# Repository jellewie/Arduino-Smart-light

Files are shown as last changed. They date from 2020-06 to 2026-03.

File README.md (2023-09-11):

# Smart clock
A smart 3D printed light clock/lamp, that includes, but is not limited to; WIFI and manual control, Clock mode, multiple animations, and transitions.

If you have interest in buying one and live in The Netherlands, feel free to contact me.

You can skip to [Quick start guide](#quick-start-guide) if you already own a smart-clock, and just want to run the set-up.

You can skip to [OTA updater](#ota-over-the-air-update) if you just want to update it.

# Index
<details><summary>Show/hide</summary><p>

 - [Quick start guide](#quick-start-guide)
 - [Creating a unit](#creating-a-unit)
    - [Hardware](#hardware)
    - [Creating the model](#creating-the-model)
       - [Desk model](#desk-model)
       - [Wall model](#wall-model)
          - [3D printed only](#3d-printed-only)
          - [CNC](#cnc)
    - [PCB & wires](#pcb--wires)
    - [Firmware ](#firmware)
       - [Compile](#compile)
       - [BIN](#bin)
 - [Features](#features)
    - [Button](#button)
    - [LED status](#led-status)
    - [Potentiometer](#potentiometer)
    - [WIFI page](#wifi-page)
       - [Setup](#setup)
       - [Getting it’s IP](#getting-its-ip)
       - [Control](#control)
       - [Soft settings](#soft-settings)
       - [Clock mode](#clock-mode)
       - [Task List](#task-list)
       - [OTA (Over The Air update)](#ota-over-the-air-update)
       - [Full reset](#full-reset)
 - [Specifications ](#specifications)
    - [Input voltage](#input-voltage)
    - [Power consumption](#power-consumption)
 - [Appendix](#appendix)
</p></details>

# Quick start guide
Follow the following steps to setup the lamp, stop after the first step if you do not want to set up Wi-Fi.
1.	Connect a proper power supply. The LEDs will blink shortly a soft white for a split second to show that bootup was successful.
2.	The [potmeters](#pot-meter) or [button](#button) will change the light.

**Optional for WIFI:**
1.	Long press the button, this will make the LEDs go PURPLE/RED/PURPLE/RED this means it is trying to connect to Wi-Fi, if this takes more than 10 seconds it will have created an Access Point. (Long press the button again to cancel this setup)
2.	Connect to this Access Point, by default it will be called “smart-clock”.
3.	When connected go to [192.168.4.1](http://192.168.4.1/) this will show a page where the WIFI name (SSID) and password (Password) can be set, do not forget to submit to apply. Other settings on this page are explained in [soft settings](#soft-settings), for example 'Clockoffset' is the rotation of the LEDs (there are 60 LEDs so filling in 30 will rotate the clock by 50%). 
~~The light will also try to make a captive portal to prompt you to login and setup these settings. Sadly, this only works with HTTP, use the mentioned IP if the device does not prompt the login page ([Not working as of now, Known issue](https://github.com/jellewie/Arduino-Smart-light/issues/28))~~ 
4.	When the device is connected to WIFI it can be accessed by its IP address, but on devices who support mDNS, like Windows and Apple, [smart-clock.local/](http://smart-clock.local/) can also be used.

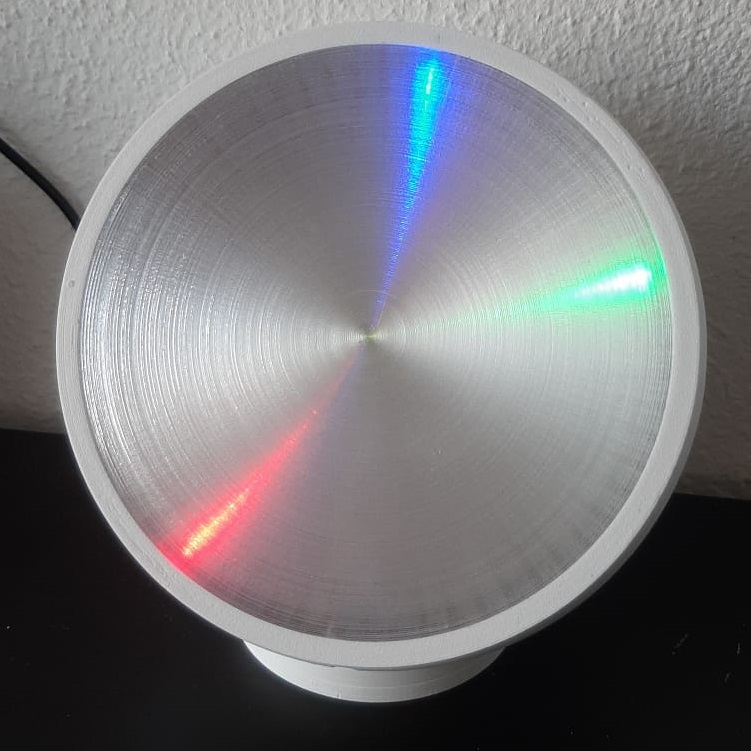
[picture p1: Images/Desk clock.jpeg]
Desk clock image

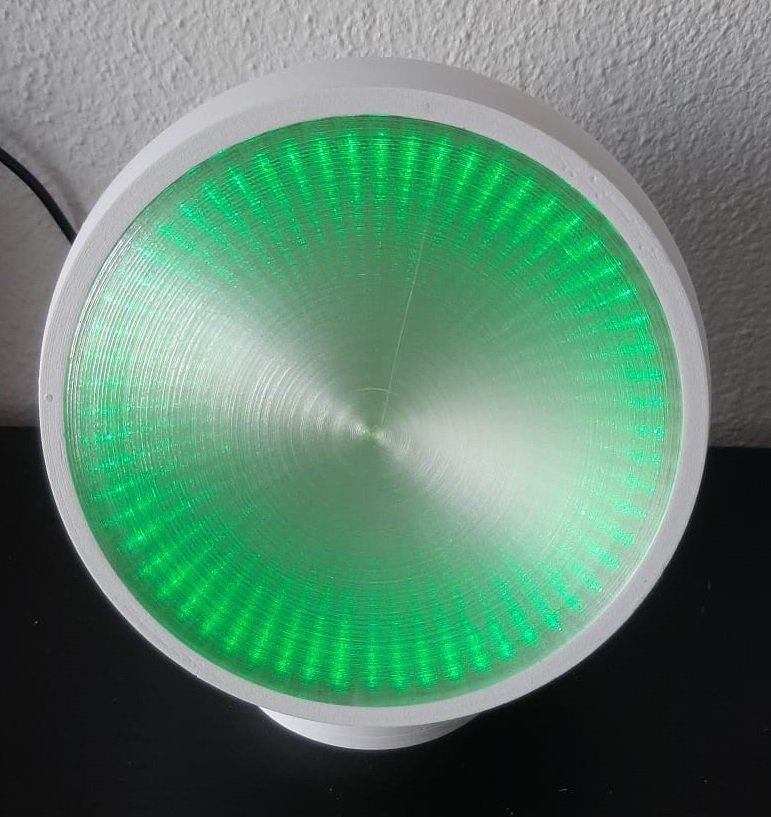
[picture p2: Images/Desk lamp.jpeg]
Desk lamp image


# Creating a unit
## Hardware
- A [PCB for the lamp/wall model](https://easyeda.com/jellewietsma/smart-light), or a lot of patient copying the schematic and doing it by hand.
- Parts listed in the [BOM](BOM.md) (or the BOM on EasyEDA), these include resistors, capacitors, buttons, potmeters, and an ESP32 as examples.
- An [model](#creating-the-model) to put everything in. This can either be completly 3D printed, or CNCed, and can also differ in model itzelf like the [DESK](#desk-model) or the [WALL](#wall-model) model.

## Creating the model
There multiple types of model, the '[DESK model](#desk-model)' is used in this readme as example project. But the other models have the same features, just a different shape. 

All STL files for 3D-printing have a predefined tolerance of 0.2mm build-in.
### Desk model
The model is [Desk.ipt](3DModel/Desk/Desk.ipt), for this model there are 4 files that need to be printed.
1.	[Lamp body.stl](3DModel/Desk/Body.stl) is the main body. It is suggested to do at least (0.4mm*3lines=1.2mm) walls so light will not shine though as much. It is printed on its face (like the STL orientation) and only the inner part needs a bit of support (overhang angle 90 degrees, density 2%).
2.	[Lamp shield.stl](3DModel/Desk/Shield.stl) is just a simple shield to add aluminium foil on, and will be intern so can be printed quick and dirty.
3.	[Lamp stand.stl](3DModel/Desk/Stand.stl) can have 3 times a pair embedded magnets in it, if the magnets are desired a layer pause need to be used. this model should be printed in the normal standing position on the round flat part.
4.	[Diffuser.gcode](3DModel/Desk/Diffuser.gcode) A perfect spiral Gcode, this can be created with [Jespers Perfect Spiral-Gcode](https://github.com/jespertheend/spiral-gcode). Altough a STL file is also included.

### Wall model
This model and PCB is 'Work In Progress'!

There are 2 variants, and fully 3d printed model, and a CNC model.

#### 3D printed only
The model is [Wall Clock.ipt](3DModel/Wall/Wall%20Clock.ipt), for this model there are 2 files that need to be printed.
1.	[Clock Top.stl](3DModel/Wall/Clock%20Top.stl) This is the top of the clock, which houses the PCB controls.
2.	[Clock x2.stl](3DModel/Wall/Clock%20x2.stl) This needs to be printed twice, and is the bottom left and right.

#### CNC
The model is [Wall Clock CNC.ipt](3DModel/Wall/Wall%20Clock&20CNC.ipt).
1.  [Wall Clock CNC.ipt](3DModel/Wall/Wall%20Clock&20CNC.ipt) This is the part that needs to be cut, it has thicker walls and no LED seperates
2.	The CNC .ipt mentioned above does have hidden LED seperates in the file, the idea was to 3d print them but this is still a WIP idea thing.

## PCB & wires
Please refer the in the [appendix](#appendix) - PCB & schematic for the schematic, but here are some common notes about the schematic, for example in [Input voltage](#Specifications) and [power consumption](#power-consumption) more information is given about the specifications of the electrics.

## Firmware 
The firmware needs to be flashed once to enable [OTA](#ota-over-the-air-update) BIN file upload. Either with Arduino IDE and compile it, or using a BIN uploader of choice.

### Compile
- [Arduino sketch](Arduino) The whole sketch is the 'Arduino' folder.
- [ESP32](https://dl.espressif.com/dl/package_esp32_index.json) must be added as an additional board manager in Arduino IDE.
- [FastLED](https://github.com/FastLED/FastLED) can be downloaded though the built-in library anager in Arduino IDE.

- [Arduino-WIFIManager](https://github.com/jellewie/Arduino-WiFiManager) (already included).
- [Arduino-Button](https://github.com/jellewie/Arduino-Button) (already included).
- [Arduino-Stable-analog-read](https://github.com/jellewie/Arduino-Stable-analog-read) (already included).

### BIN
Uploading a BIN file with a cable to the ESP can be done by any [ESP32 BIN file uploader](https://www.espressif.com/en/support/download/other-tools). this step is required for the first flash time.

The BIN files themself can be found at [releases](https://github.com/jellewie/Arduino-Smart-light/releases). The newest version is always recommended and can be updated with [OTA](#ota-over-the-air-update).

# Features
## Button
Although these options change a bit over time, here is a list of 3 actions what the button generally does, these can also change in different modes.
1.	**StartPress** Triggered when you start a press, will be rejected if sooner than Time_RejectStarts (80ms) of the last press).
- Will toggle the lamp ON/OFF
2.	**StartDoublePress** Triggered when you start a second press between Time_RejectStarts (80ms) and Time_StartDoublePress (200ms) after the last one ended.
- Will change the mode to 'DoublePressMode' (RAINBOW by default)
3.	**StartLongPress** Triggered when you press the button longer than Time_StartLongPressMS (5000) but shorter than Time_ESPrestartMS (15000) ms.
- If in APmode it will cancel and reboot.
- If it was connected to WIFI it will show its IP, Which is explained in [WIFI page](#wifi-page) - Getting it’s IP.
- If it isn’t connected to WIFI it will start connecting to WIFI (and possibly go into AP mode, that is explained in 

## LED status
In the back of the [desk](#desk-model) model is a LED (below the button). This is also the LED on the PCB of the ESP (LED_BUILDIN) this LED reflects thes errors:
- **ON** WIFI starts, goes OFF when WIFI setup is successfully completed.
- **blink 100ms** WIFI setup failed, APmode has started.
- **blink 2000ms** WIFI is lost, so the current time (we are in CLOCK mode) cannot be updated.
- **blink 500ms** it is connecting to the given WIFI.

Some statuses are also reflected by the LED strip itself, but due to the difficulty driving these in some WIFI modes, these are static set at the start of the status.
- **White short blink** It is booting up.
- **PURPLE/BLUE/PURPLE/BLUE** It is starting the WIFI connect code.
- **PURPLE/RED/PURPLE/RED** It is starting the Access Point code (WIFI could not connect).
- **PURPLE/GREEN/PURPLE/GREEN** It is starting the get server time code.

## Potentiometer
The 4 Potentiometers are Red, Green, Blue, and White. Where white stand for the luminescence. 
When any of the RGB Potentiometers are turned the mode will switch to on/manual and the RGB value will be shown.

## WIFI page
The 2 most important pages are the [Setup](#setup) page, where the user can setup the light. And the [main landing page](#control) where the UI is that the user uses to contol the smart-clock.

### Setup
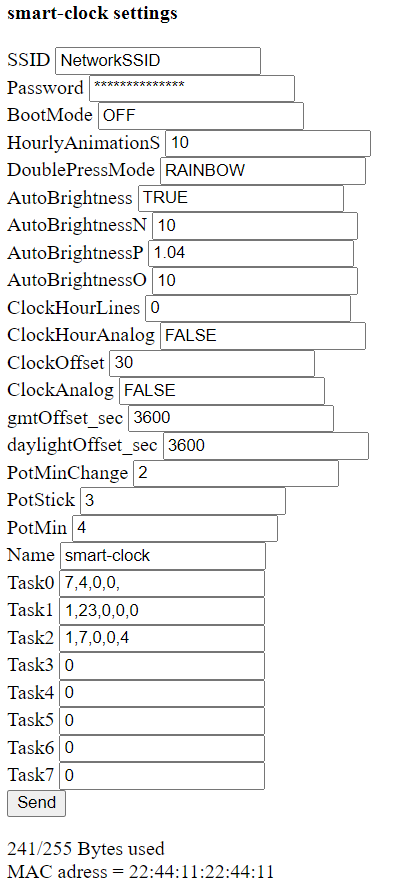
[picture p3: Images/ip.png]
WIFI page /ip


The setup page will be accessible and shown in APmode, but can also be access by going to [smart-clock.local/ip](http://smart-clock.local/ip). An example of this page is shown in the figure on the right.
The password is replaced with starts, and cannot be received without changing the firmware. 
Leave fields blank (or for the password leaving only stars) to not update those values upon sending this forum.
By default the SSID and password is limited to 16 characters by the firmware, and the total bytes that can be stored in memory is limited to 128. Going over these values results in unexpected behaviour. 

### Getting it’s IP
User devices that support mDNS, like Windows and Apple, can use [smart-clock.local/info](http://smart-clock.local/info) to obtain its IP.

Alternatively the IP can be shown in the LEDs themself. To trigger this see [Button](#Button).
The LEDs are divided into 10 sections, and each byte in the IP range will be shown one at a time, to goto the next section press the button shortly again. The numbers are like a clock and in clockwise direction, top/right is 0 and the one right/down of that is 1. Where RGB will be the order of the numbers, so red will have a x100 multiplication and green will have x10, so when the IP is 198.168.1.150 and it shows the last section (150) then section 1 will be Red, 5 will be green and 0 will be blue. This is shown in the figure below

ShowIP 198.168.1.150

### Control
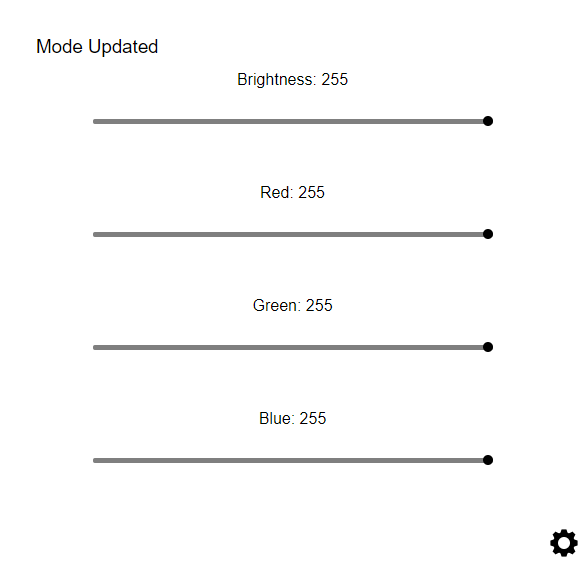
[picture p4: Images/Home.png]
Home page

The control page is the default landing page the user will land on. An example of this page is shown in the figure on the right.

- **The brightness slider** will always change the brightness no matter in what mode it is in (except for AP since that is not a defined mode), these values are only send and updated on releasing the slide bar. This will also turn off auto brightness.
- **The RGB sliders** will either (try) change the animation accent to the given RGB colour, or switch the mode to Wi-Fi control and set the RGB colour.
- **Settings button** The gear on the right lower corner will open the settings page.

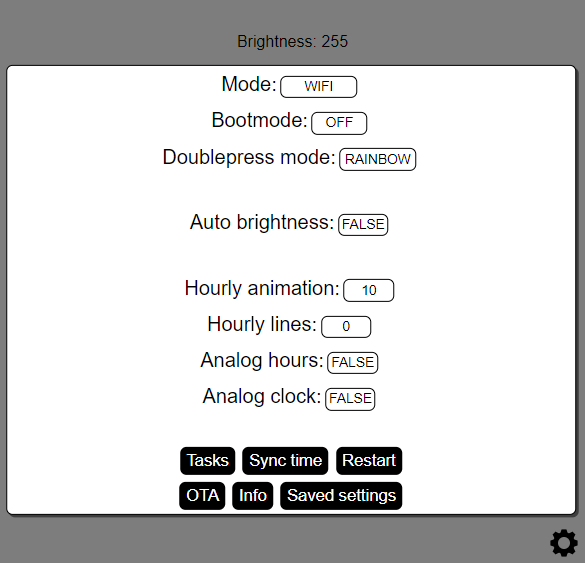
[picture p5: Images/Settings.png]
Settings page

An example of the settings page is shown in the figure on the right.

- **Mode** is the current mode the light is in.
- **Bootmode** is the mode the light will go into on start-up. Altough not all modes are visible on the webpage it supports all modes. To do this a custom webrequest needs to be made (in this case and in the time of writing [smart-clock.local/set?m=MOVE](smart-clock.local/set?m=MOVE)).
- **Doublepress mode** is the mode the light will switch to when a double press on the button is made.
- **Auto brightness** will set the brightness automatically.
- **Hourly animation** is when the light is in the clock mode an hourly animation needs to be played.
- **Hourly lines** when in clock mode, will add lines to each hour, the value is the amount on a byte scale (0-255) dimmed by the brightness itself..
- **Analog hours** will let the hour indicator take 60 instead of 12 steps, so it will not stick to the whole hours indication.
- **Enable OTA** will direct to the [OTA](#ota-over-the-air-update) update page, where the firmware can be updated over the WiFi.
- **Sync time** will get the current updated time from the server, this function is called automatically every day on 04:00 if the light is in clock mode.
- **Reset** will fully restart the ESP.
- **Info** will open the info page with some information like the version compile date.
- **Task** this will show a task menu, so tasks can be scheduled or removed.
- **Saved settings** just redirects you to [smart-clock.local/ip](http://smart-clock.local/ip) to show you the values saved in the EEPROM.

### Soft settings
There are multiple soft settings, these are settings that can be changed after the sketch has been uploaded, but are still saved so they can be restored after a reboot.
The most up-to-date values can be found in the top of the [WiFiManagerBefore.h](Arduino/WiFiManagerBefore.h) source file, and can only be set in [smart-clock.local/ip](http://smart-clock.local/ip).
These settings are saved EEPROMSaveDelayMS (Default 30000ms) after the last change of SoftSettings, or directly after APmode and in the [smart-clock.local/ip](http://smart-clock.local/ip) page.
Note that the character " and TAB (EEPROM_Seperator) cannot be used, these will be replaced with ' and SPACE respectively. Leave black to skip updating these, use spaces ' ' to clear the values
- **Bootmode** In which mode to start in after start-up
- **HourlyAnimationS** If it needs to show hourly animations when in CLOCK mode, defined in time in seconds where 0=off.
- **DoublePressMode** In what mode to go into when the button is double pressed.
- **AutoBrightness** Turns on brightness if enabled, the curve of which can be set with N and P.
- **AutoBrightnessN** Used to calculate auto brightness =P*(X-N)+O. please see https://www.desmos.com/calculator/5tpxxofamn
- **AutoBrightnessP** ^ Just the lowest raw sensor value you can find
- **AutoBrightnessO** ^ Just a brightness offset, so it can be set to be globally more bright
- **ClockHourLines** how bright each hour mark needs to be on a scale of 0 (OFF) to 255.
- **ClockHourAnalog** Will use all 60 LEDs to display the hour, not just stick to wholes and use 12.
- **ClockOffset** Number of LEDs to offset/rotate the clock, so 12 o'clock would be UP. Does NOT work in Animations.
- **ClockAnalog** Makes it so the LEDs do not step but smoothly transition. This does cost considerable more processing power. Makes ClockHourAnalog useless. https://www.desmos.com/calculator/zkl6idhjvx
- **timeZone** Set to you Timezone, see https://github.com/nayarsystems/posix_tz_db/blob/master/zones.csv, for example "CET-1CEST,M3.5.0,M10.5.0/3" for Amsterdam (DEFAULT)
- **RESERVED**
- **PotMinChange** How much the pot_value needs to change before we process it.
- **PotStick** If this close to HIGH or LOW stick to it.
- **PotMin** On how much pot_value_change need to change, to set mode to manual.
- **Name** The mDNS, WIFI APmode SSID, and OTA name of the device. This requires a restart to apply, can only be 16 characters long, and special characters are not recommended.
- **Task#** 8 tasks (0-7), the format is described in [task-list](#task-list)

### Clock mode
For the use of clock mode the right time zone needs to be set up, these are stored in timeZone (Default to Amsterdam). 

Clock mode can only be started when WIFI has been connected and the user switches mode, after switching to Clockmode the lamp will turn PURPLE/GREEN/PURPLE/GREEN this means it is getting the time from a time server.

Also the clock can be manual updated with [smart-clock.local/time?h=3&m=59&s=50](http://smart-clock.local/time?h=3&m=59&s=50) where H is hours, M is minutes, and S is seconds. The clock also automatically updates every day at 4:00

Furthermore the clock has some softsettings like ClockHourLines, but these are descibed in [Soft settings](#soft-settings)

### Task List
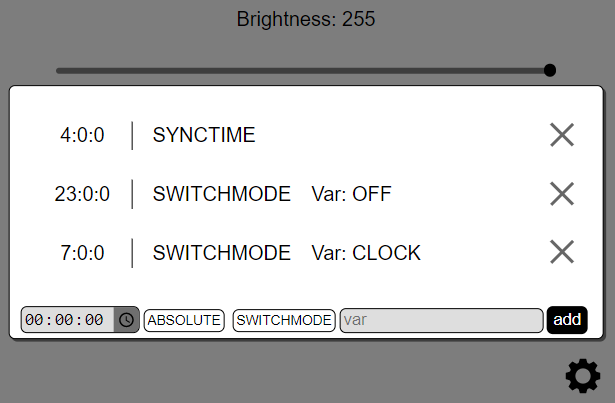
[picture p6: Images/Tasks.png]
Tasks page

This page can be accessed on by opening the settings menu and clicking on the button 'Tasks'
There can be 16 tasks, and the first 8 will be saved to EEPROM and will be restored after boot. 
By default the SYNCTIME had been added at 4:0:0

The format of Tasks "TimeH,TimeM,TimeS,TaskType,Var"
- I, the number in the list (0-15) assigned automatically 
- Time, 3x in the format of HH:MM:SS "x,y,z" |OR| time in ms to execute "w" (w are not saved in EEPROM)
- TaskType, the type of task and automatically converted to show the name. (see TaskString in Task.h)
- Var, this can be a custom variable (few examples are given below)

Some examples of TaskType and Var:
	TaskType (x but converted to name) - Var (x but can be converted to name)
1. SWITCHMODE - New mode to switch to "x" either in string or ID form 
2. DIMMING - Stepsize,GoTo,TimeInterfall in ms "x,y,z"
3. BRIGHTEN - Stepsize,GoTo,TimeInterfall in ms "x,y,z"
4. RESETESP
5. CHANGERGB - Red,Green,Blue,OPT_Brightness "x,y,z" |OR| "x,y,z,w"
6. SAVEEEPROM
7. SYNCTIME
8. AUTOBRIGHTNESS - True/false "x" either in string or ID form 
9. HOURLYANIMATIONS - Time in seconds for the animation "x" 

### OTA (Over The Air update)
This page can be accesed on [smart-clock.local/ota](http://smart-clock.local/ota) (or 'IP/ota') and enables you to update firmware over WiFi.
On this page is a 'choose file' button where the new version can be selected. Make sure the right, compatible, most updated file is selected ("Smart_clock.bin"). This can be downloaded from [releases](https://github.com/jellewie/Arduino-Smart-light/releases). 
After which the 'Upload' button needs to be press for the update process to begin, the unit will automatically update and reboot afterwards.
Note that [SoftSettings](#soft-settings) are preserved.

### Full reset
If a full reset is desired it can be achieved by going to 'smart-clock.local/reset'. But note that accessing the page will directly wipe all [SoftSettings](#soft-settings) from existence and there will be no way to restore them back. If the wipe was successful it will be reported back and will execute a restart.

# Specifications 
## Input voltage
The power supply is either 5V or 12V. The difference in the voltage is the used LED strip. If the WS2812B is used it would need to be 5V, but if the WS2815 (with redundant data lines) is used then 12V is required.

positive polarity

The pinout of the DC jack has by default positive polarity. Meaning the outer tube -as shown in the figure right- is the ground connection. The lamp will fail to work otherwise (but is able to handle the shock).
## Power consumption
The lamp will consume 18Watts at maximum, so as an example for 12V a 1.5A (or 5V at 3.6A) power supply is required to allow full brightness. Although actual measurements came closer to 12Watt.

The idle power consumption is about 0.65Watt (measured with LEDs turned off, and WIFI turned on)

# Appendix
* Firmware
[This is included in this repository](Arduino)
* PCB & schematic
[This is included in this repository](Schematic-PCB)
Beta/ updated version on [EasyEDA](https://easyeda.com/jellewietsma/smart-light)
* 3D models
[These are included in this repository](3DModel)
* BOM
[This is included in this repository](BOM.md)

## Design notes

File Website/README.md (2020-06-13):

This is just the HTML version, please see the Arduino code for the most current file, altough this should be the same as a backup
The code is written by [@JesperTheEnd](github.com/jespertheend)

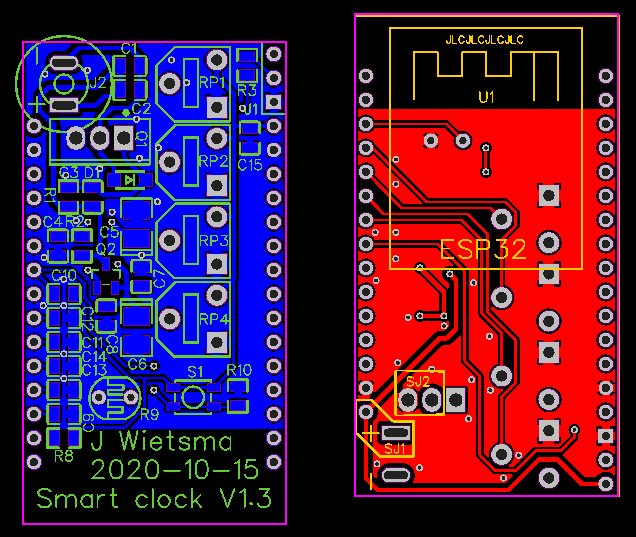
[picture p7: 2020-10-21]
Schematic PCB/V1.3 Wall PCB.png

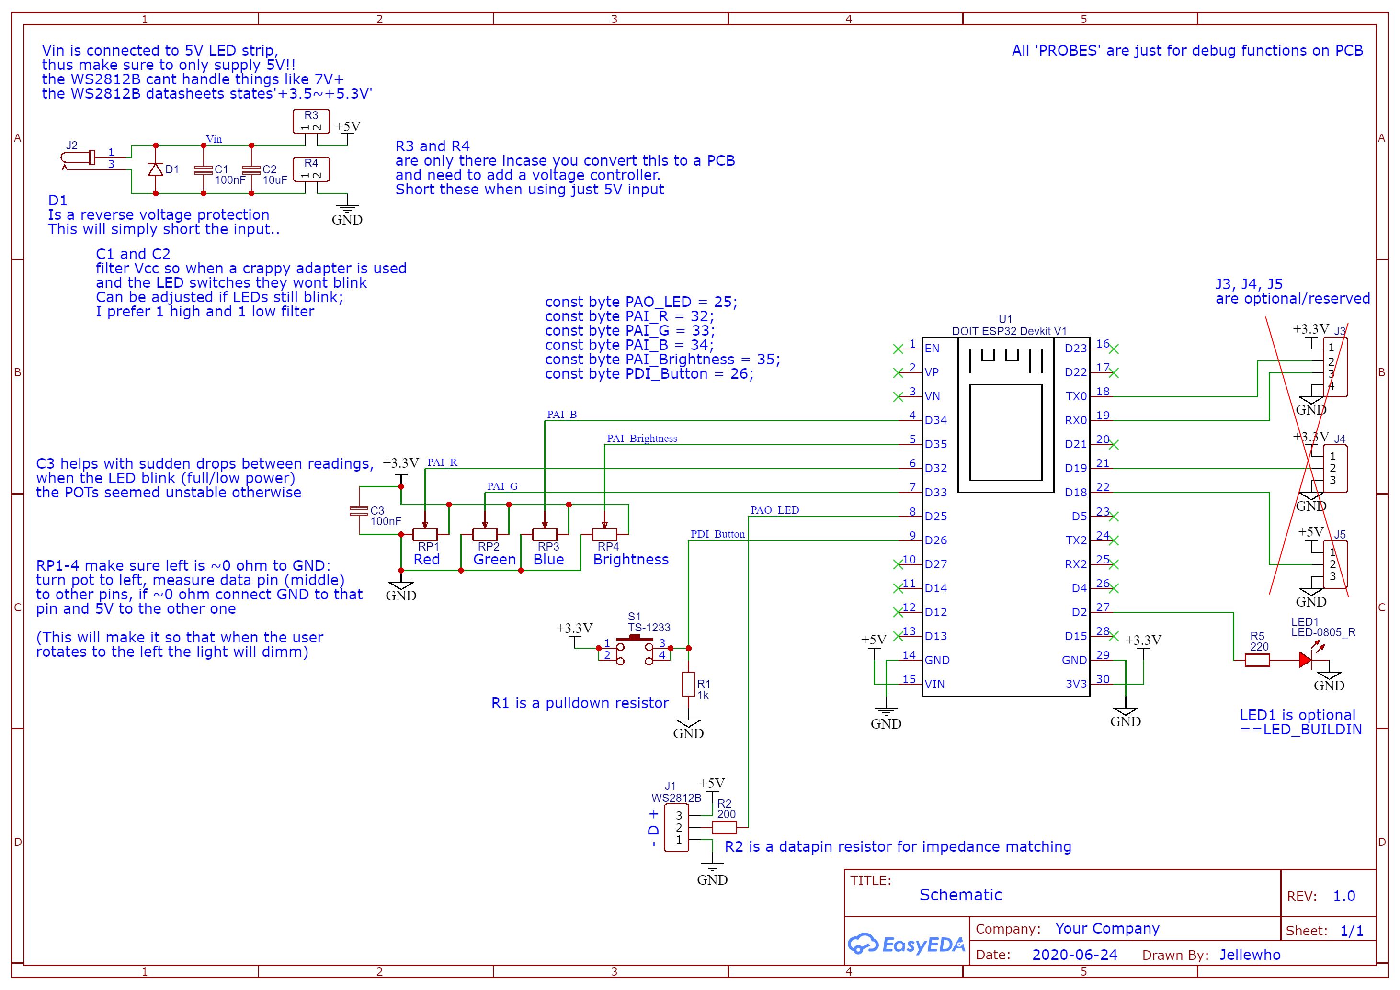
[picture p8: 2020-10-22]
Schematic PCB/V1.0 Schematic.png

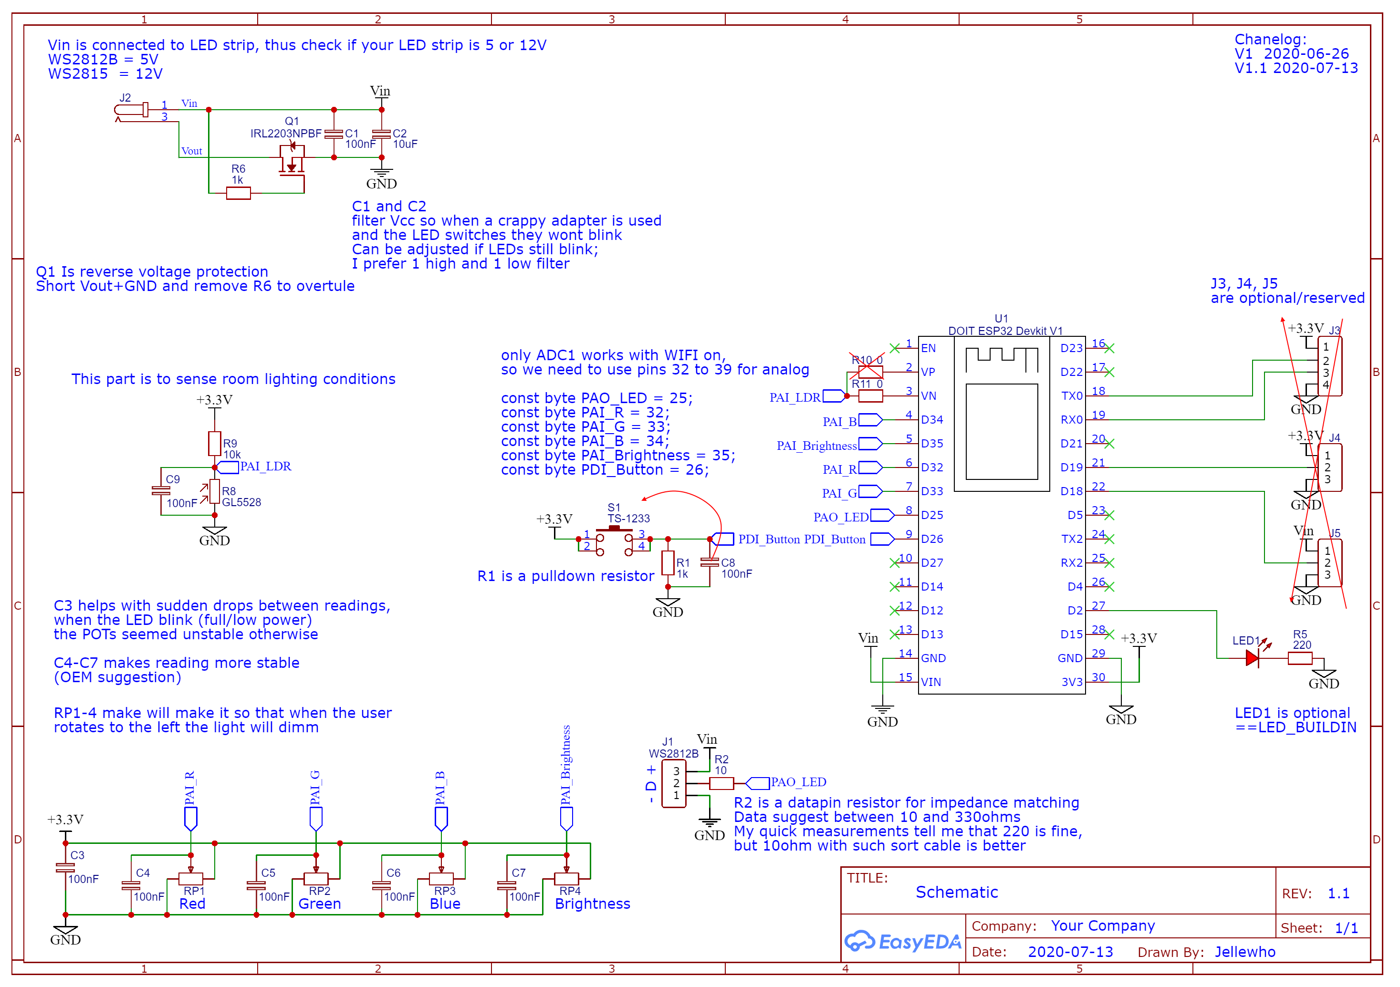
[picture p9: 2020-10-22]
Schematic PCB/V1.1 Schematic.png

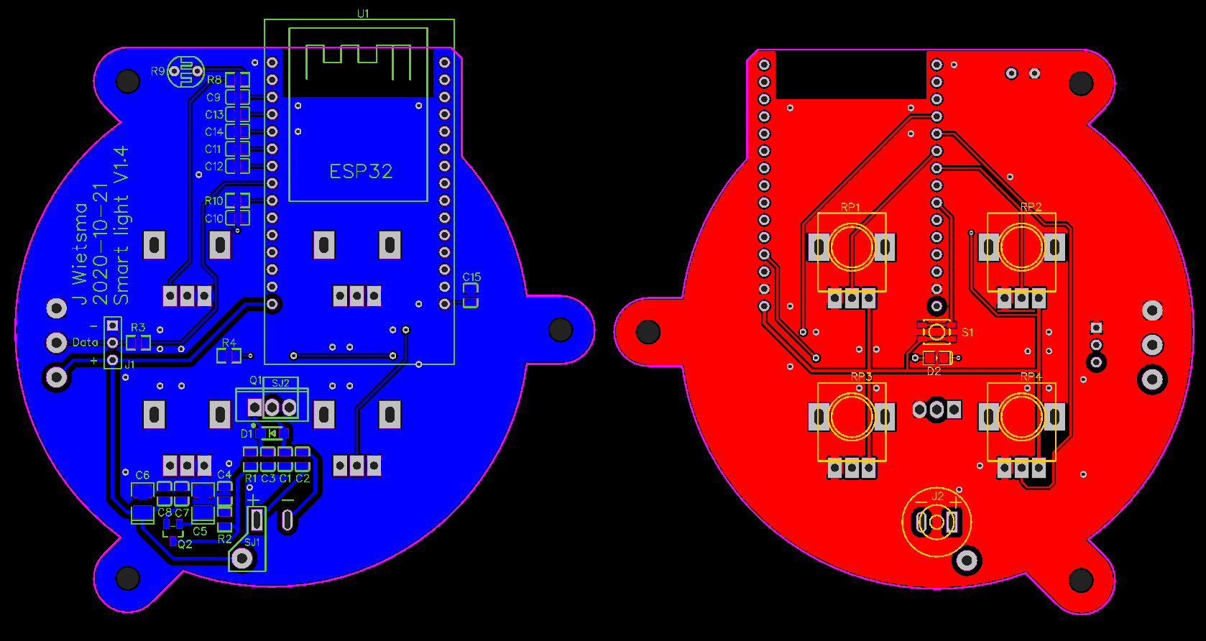
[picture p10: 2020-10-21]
Schematic PCB/V1.4 Desk PCB.png

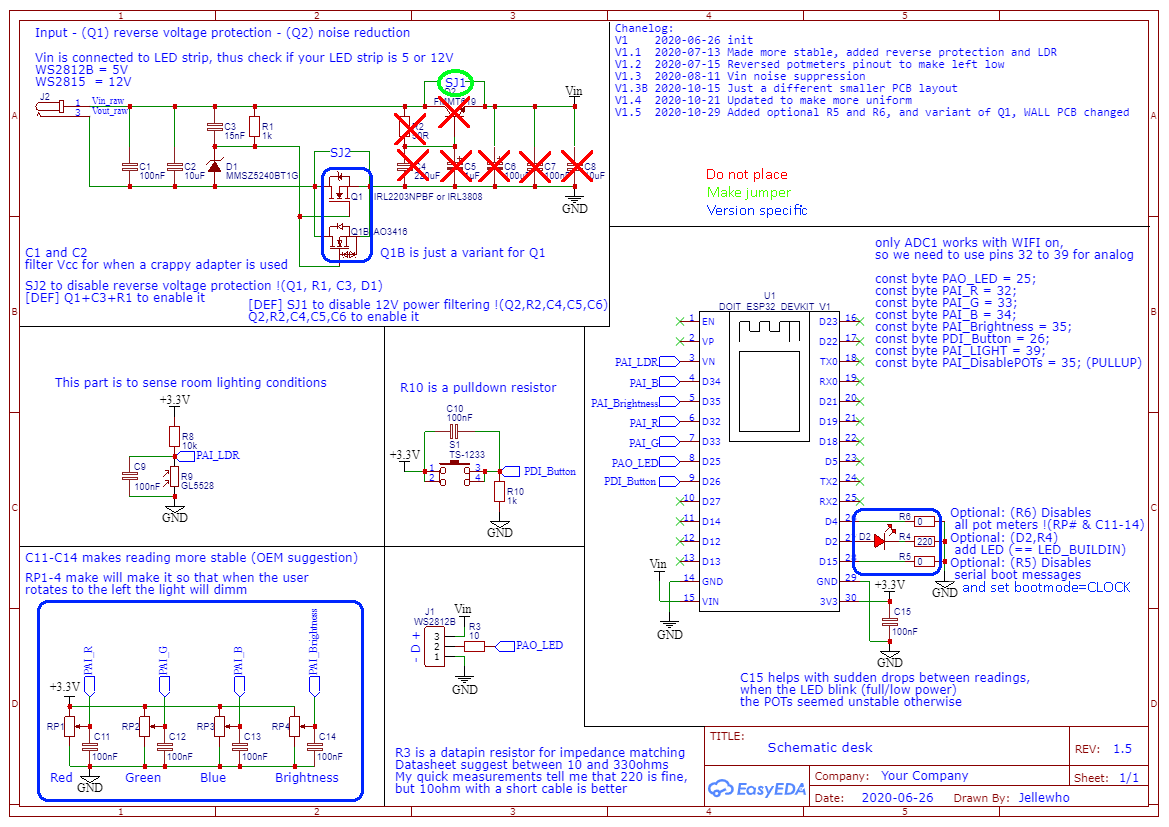
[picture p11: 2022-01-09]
Schematic PCB/V1.5 Schematic.png

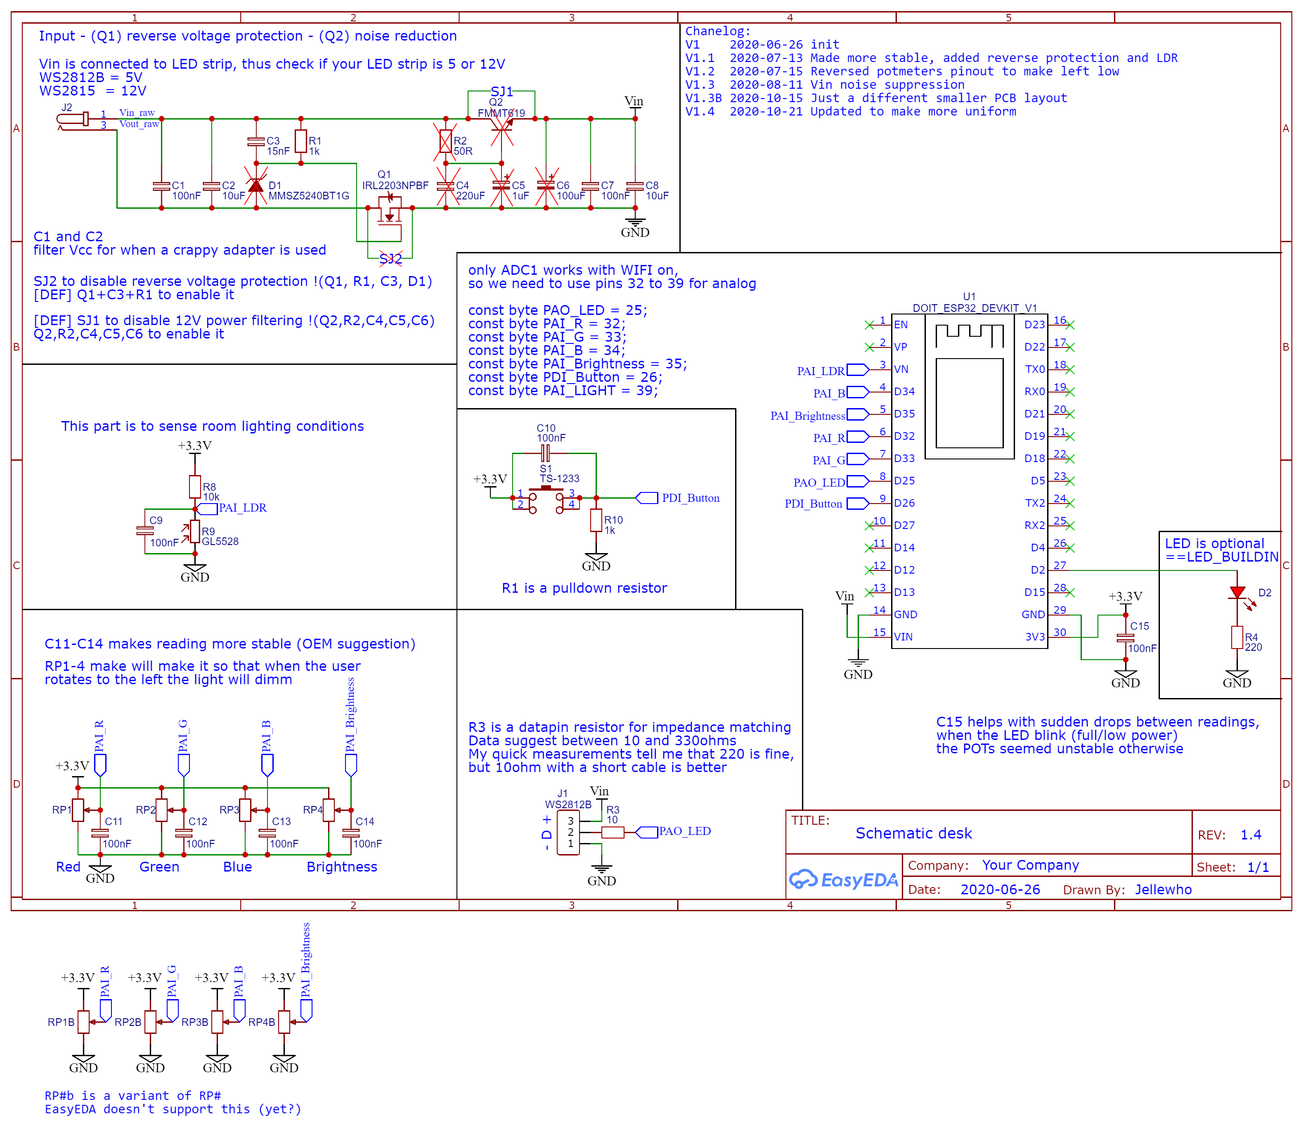
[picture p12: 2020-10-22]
Schematic PCB/V1.4 Schematic.png

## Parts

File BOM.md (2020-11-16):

This BOM list all the parts that are required to make a smart-light. It also list what parts are model specific.
Tools, solder, flux, time, developing, etc are not included.		

| Only for model | Description | Amount | Designator | Link	
| --- | --- | --- | --- | ---
|  | LED strip WS2812B | 60 |  | [aliexpress.com/item/2036819167.html](https://aliexpress.com/item/2036819167.html)	
|  | USB kabel USB-A to DC2.2mm*5.5mm | 1 |  | [aliexpress.com/item/32934383650.html](https://aliexpress.com/item/32934383650.html)	
| DESK | Magnets 4xØ10mm | 6 |  | [aliexpress.com/item/1005001531049391.html](https://aliexpress.com/item/1005001531049391.html)	
| DESK | Insert nut M3 | 3 |  | [aliexpress.com/item/33008141694.html](https://aliexpress.com/item/33008141694.html)	
| DESK | Insert bolt + spacer | 3 |  | 	
| DESK | Potentiometer knob (in colors RGBW) | 4 |  | [aliexpress.com/item/32928287473.html](https://aliexpress.com/item/32928287473.html)	
| DESK | 3D print - Body | 1 |  | ~220gram ~18uur	
| DESK | 3D print - Stand | 1 |  | ~30gram ~2,5uur	
| DESK | 3D print - Shield | 1 |  | ~35gram ~2,5uur	
| DESK-A | 3D print - Difuser | 1 |  | ~40gram ~3uur	
| DESK-B | Difuser PRIMO | 1 |  | [pyrasied.nl/product/primo-xt-n381-mat-satijn-2mm-lt71/](https://pyrasied.nl/product/primo-xt-n381-mat-satijn-2mm-lt71/)	
| WALL-3D | 3D print - Top | 1 |  | ~42gram ~3,5uur	
| WALL-3D | 3D print - Side | 2 |  | ~30gram ~3uur	
| WALL-CNC | Wood frame + CNCing | 1 |  | 	
|  | PCB  | 1 |  | [jlcpcb.com/order](https://jlcpcb.com/order)	
|  | DOIT ESP32 DEVKIT V1 | 1 | U1 | [aliexpress.com/item/32959541446.html](https://aliexpress.com/item/32959541446.html)	
|  | Mosfet IRF3808PBF | 1 | Q1 | [aliexpress.com/item/32967801317.html](https://aliexpress.com/item/32967801317.html)	
|  | LDR 5528 5mm | 1 | R9 | [aliexpress.com/item/32996322231.html](https://aliexpress.com/item/32996322231.html)	
|  | Button TS1233 2,5mm SMD | 1 | S1 | [aliexpress.com/item/32947539977.html](https://aliexpress.com/item/32947539977.html)	
|  | Capacitor C0805 15nF | 1 | C3 | [aliexpress.com/item/32998981034.html](https://aliexpress.com/item/32998981034.html)	
|  | Capacitor C0805 100nF | 9 | C9, C11, C12, C13, C14, C15, C7, C1, C10 | [aliexpress.com/item/32998981034.html](https://aliexpress.com/item/32998981034.html)	
|  | Capacitor C0805 10uF | 2 | C8, C2 | [aliexpress.com/item/32998981034.html](https://aliexpress.com/item/32998981034.html)	
|  | Resistor R0805 0 | 1 | R5 | [aliexpress.com/item/32858225842.html](https://aliexpress.com/item/32858225842.html)	
|  | Resistor R0805 10 | 1 | R3 | [aliexpress.com/item/32858225842.html](https://aliexpress.com/item/32858225842.html)	
|  | Resistor R0805 220 | 1 | R4 | [aliexpress.com/item/32858225842.html](https://aliexpress.com/item/32858225842.html)	
|  | Resistor R0805 1k | 2 | R1, R10 | [aliexpress.com/item/32858225842.html](https://aliexpress.com/item/32858225842.html)	
|  | Resistor R0805 10k | 1 | R8 | [aliexpress.com/item/32858225842.html](https://aliexpress.com/item/32858225842.html)	
| DESK | DC jack DC-022B (DC-IN-TH_DC-022B-2.0)  2.2mm*5.5mm | 1 | J2 | [aliexpress.com/item/32962556698.html](https://aliexpress.com/item/32962556698.html)	
| DESK | LED white C0805 | 1 | D2 | [aliexpress.com/item/32983794565.html](https://aliexpress.com/item/32983794565.html)	
| DESK | Potentiometer RV09 10K | 4 |  | [aliexpress.com/item/4000078097697.html](https://aliexpress.com/item/4000078097697.html)	
| WALL | Potentiometer RM065 10K | 4 |  | [aliexpress.com/item/4000806028470.html](https://aliexpress.com/item/4000806028470.html)

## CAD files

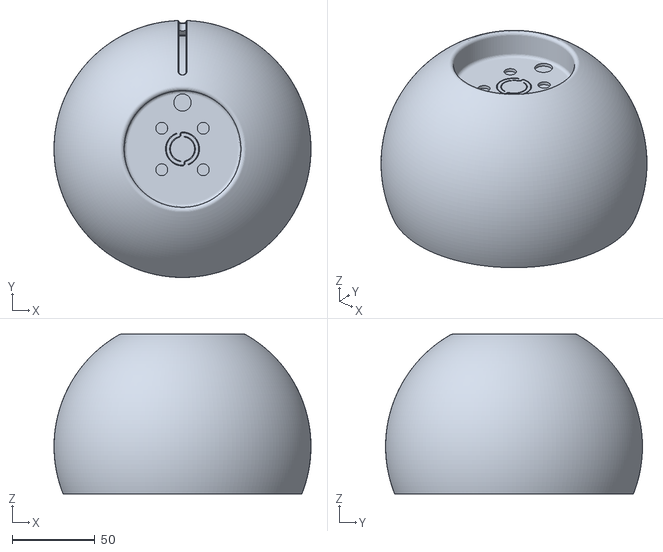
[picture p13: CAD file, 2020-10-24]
3DModel/Desk/Body.stl
155.0 x 155.0 x 96.3

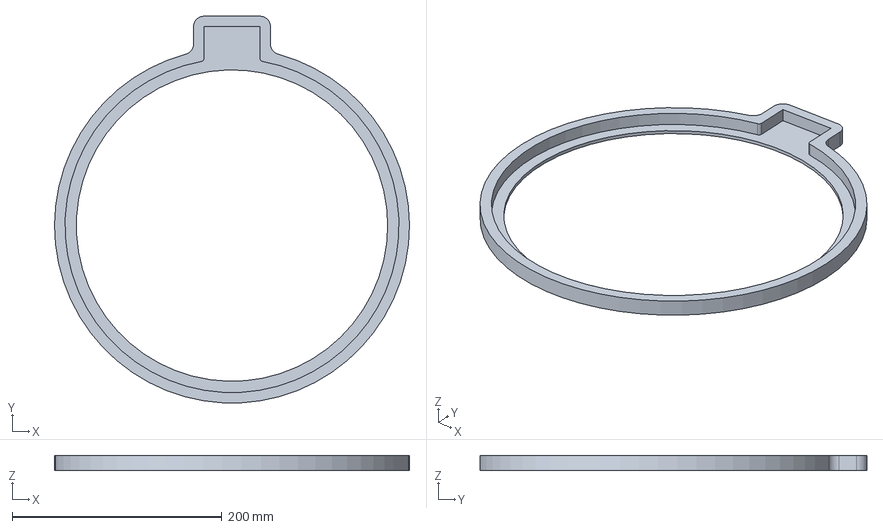
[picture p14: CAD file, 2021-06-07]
3DModel/Wall/Wall Clock CNC.stp
338.5 x 368.6 x 14.2 mm

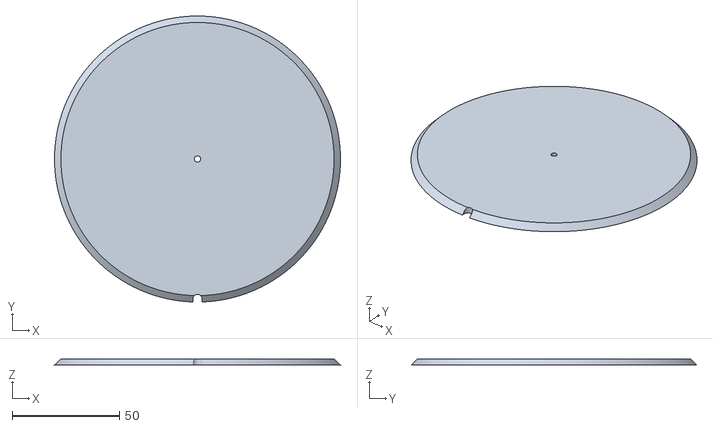
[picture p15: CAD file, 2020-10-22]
3DModel/Desk/Shield.stl
133.3 x 133.2 x 3.00

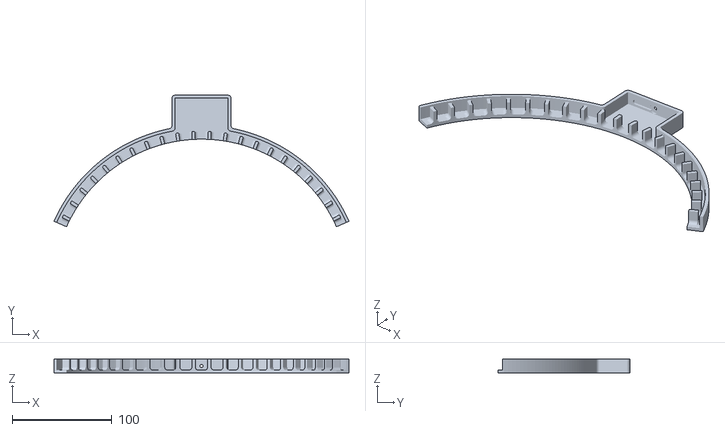
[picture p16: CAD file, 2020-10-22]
3DModel/Wall/Clock Top.stl
296.4 x 132.3 x 14.2

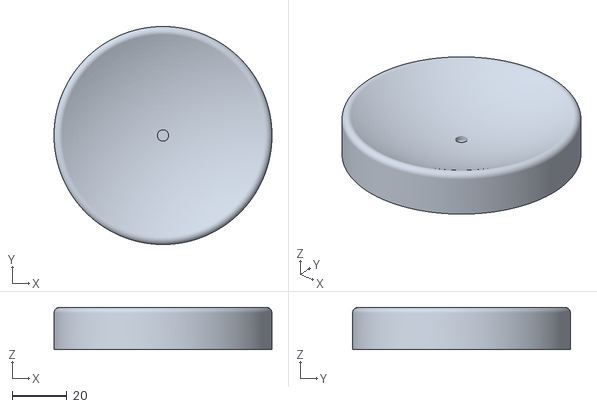
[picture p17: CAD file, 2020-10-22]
3DModel/Desk/Stand.stl
80.0 x 80.0 x 15.4

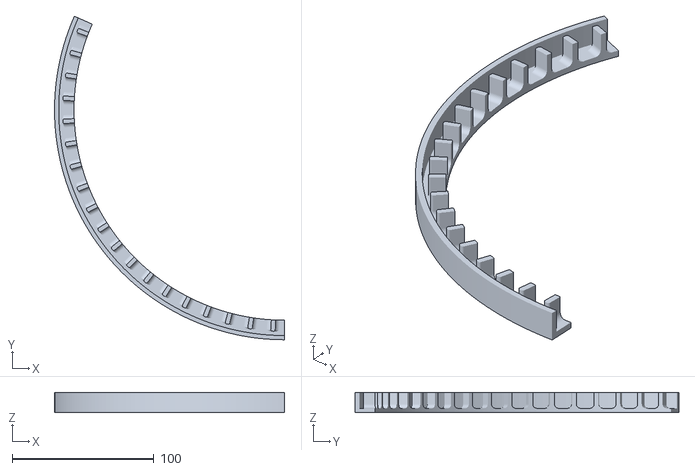
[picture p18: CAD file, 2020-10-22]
3DModel/Wall/Clock x2.stl
162.2 x 228.2 x 14.2

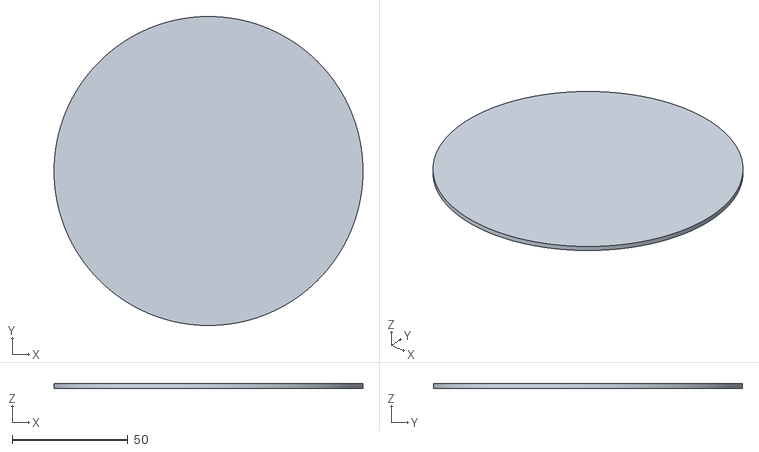
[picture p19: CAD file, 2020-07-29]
3DModel/Desk/Difuser.stl
133.3 x 133.3 x 2.00

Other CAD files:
3DModel/Desk/Assembly.iam
3DModel/Desk/Desk.ipt
3DModel/Desk/PCB.ipt
3DModel/Wall/Assembly 3D printed only.iam
3DModel/Wall/Assembly CNC.iam
3DModel/Wall/PCB.ipt
3DModel/Wall/Wall Clock CNC.ipt
3DModel/Wall/Wall Clock CNC.stl
3DModel/Wall/Wall Clock.ipt

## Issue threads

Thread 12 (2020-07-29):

analog animation in clock

jellewie, 2020-07-29:
So that the seconds just move smoothly around, instead of 60 instant jumps. this would require some math and a for loop through all the pixels or something

- [x] Add animation
- [x] Test it
- [x] Add the documentation

jellewie, 2020-07-30:
https://www.desmos.com/calculator/lx3ucoymy4

jellewie, 2020-08-13:
So yes this is possible, but then we need to count milliseconds instead of only update on whole seconds. But the code isn't written to allow this to be implemented easily.

```
for (int i = 0; i < TotalLEDs; i++) {
  int BRRR = 255 - (sq(i - TimeCurrent.SS)) / 0.03;
  BRRR = constrain(BRRR, 0, 255);
  LEDs[LEDtoPosition(i)] += CRGB(0, 0, BRRR);
}
```

jellewie, 2020-08-13:
Added it anyway

Closed 2020-08-13.

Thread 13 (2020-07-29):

PCB for wall clock variant

jellewie, 2020-07-29:
Create a PCB variant for the wall clock, this will be tight, and a solution needs to be found for the sideways potentiometers

jellewie, 2020-08-11:
Test PCB is ordered

https://easyeda.com/jellewietsma/smart-clock

Closed 2020-08-11.

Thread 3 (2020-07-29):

Clock sync seems to go for ever?

jellewie, 2020-07-29:
Add timeout on clock sync request? seems to go forever now. this needs to be checked

jellewie, 2020-08-12:
Add a 'FastLED.clear()' command so the LEDs will be cleared, this bug was just visual.

Closed 2020-08-12.

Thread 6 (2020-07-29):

SSID broadcast interval

jellewie, 2020-07-29:
Check if we can do something about the time-interval of broadcast SSID in Apmode.

jellewie, 2020-07-29:
As far as I could find there is no option for it.
Still want to do another further dive into the subject, such things do exist fr BLE, and I think the broadcast time it set to low?

jellewie, 2020-08-11:
['beacon_interval' in 'AP Basic Configuration' but this does not use the Arduino ESP32 lib code, this is a level lower. the call code is 'esp_wifi_set_config() '](https://docs.espressif.com/projects/esp-idf/en/latest/esp32/api-guides/wifi.html)
This notes the AP interval defaults it to 100 ms. which is sufficient for this use case, so does not need to be changed

This is also the value the [arduino-esp3](https://github.com/espressif/arduino-esp32/blob/master/libraries/WiFi/src/WiFiAP.cpp#L121) uses 'conf.ap.beacon_interval = 100;'
which also shows that this is hardcoded

Closed 2020-08-11.

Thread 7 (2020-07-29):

CaptivePortal

jellewie, 2020-07-29:
Add a CaptivePortal to APmode?
When connecting to ApMode it would redirect you to the 192.168.4.1 directly, without the user input needed

https://github.com/espressif/arduino-esp32/blob/master/libraries/DNSServer/examples/CaptivePortal/CaptivePortal.ino

jellewie, 2020-07-29:
Some sample code

https://github.com/espressif/arduino-esp32/blob/master/libraries/DNSServer/examples/CaptivePortal/CaptivePortal.ino
    #include <DNSServer.h>
    DNSServer dnsServer;
    ? IPAddress apIP(192, 168, 1, 1);
    ? WiFi.softAPConfig(apIP, apIP, IPAddress(255, 255, 255, 0));
    dnsServer.start(53, "*", apIP); // if DNSServer is started with "*" for domain name, it will reply with provided IP to all DNS request
    dnsServer.processNextRequest();

jellewie, 2020-08-03:
Added it, but it only works for HTTP **not HTTPS** connections

Closed 2020-08-03.

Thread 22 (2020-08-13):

Test offline clock mode behavior

jellewie, 2020-08-13:
The behavior when in the clock mode, but WIFI turns off is unknown, it should in my opinion just continue to work and run, and maybe even have the LED_BUILDIN blink every 2 seconds to show it can not update

- [x] Add a blink when in clock mode but WIFI is disconnected
- [ ] Test the behavior of going offline while in clock mode

jellewie, 2020-08-20:
[getLocalTime() ](https://github.com/espressif/arduino-esp32/blob/master/cores/esp32/esp32-hal-time.c#L80)seems to also return true sometimes when wifi is disconnected? This means the 'Can not sync LED status' is not set.

Clock function itself works! it just keeps on doing its thing

Closed 2020-08-20.

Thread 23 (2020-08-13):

Toast message should be on top of settings window

jellewie, 2020-08-13:
The toast message is now below the settings window

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

# Link to source
[Arduino code](https://github.com/jellewie/Arduino-Smart-light/blob/master/Arduino/handler.ino#L177)
[HTML version](https://github.com/jellewie/Arduino-Smart-light/blob/master/Website/Index.html)

jespertheend, 2020-08-24:
Fixed in aee752f

Closed 2020-08-24.

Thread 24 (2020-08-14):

ESP restart when trying to connect to AP?

jellewie, 2020-08-14:
The ESP seems to restart when trying to connect to AP, no error is given by the terminal (USB is terminated)

jellewie, 2020-08-17:
Seems to be related to #25
This error does not occur with the 5V edition, and when I only step down the voltage beforehand, the error is gone (while it was basically always there before)

Closed 2020-08-17.

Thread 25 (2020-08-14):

AMS1117-3.3V is getting hot if 12V is used

jellewie, 2020-08-14:
The voltage regulator on the ESP32 is getting really hot (PCB V1.2, 12V input) even without the data line for the LEDs attached

- [x] Measure power consumption (For 5V it's below 0.1A) and it does not heat up
- [x] Measure consumption at 12V

- [ ] Add 'LM2596' as an option to the PCB

jellewie, 2020-08-14:
It's a linear voltage regulator, to it will burn away 12-3.3V times the current. It does work, but the life expectancy is just lower.

Maybe look into LM2596S or other switching regulators?

jellewie, 2020-08-17:
For 12V there needs to be an LM2596 in the schematic, for 5V it is fine as is.
So add 'LM2596' as an option to the PCB

harbaum, 2023-06-21:
The AMS1117 family is produced by many manufacturers. A lot of these (especially the ones rated for a higher current) are limited to an input voltage of 12V. In my experience especially the very cheap ones are really limited to 12V. They work well up to slightly over 11V. But at 12V they die even at very low currents at their output.

This can e.g. observed with many cheap arduino nano clones.

Closed 2023-03-05.

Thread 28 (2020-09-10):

CaptivePortal

jellewie, 2020-09-10:
The CaptivePortal added with ticket #7 was disabled because it was buggy, The ESP32 library has a bug that prevents it from working; The ESP reboots on client connect.

Find out how it can be fixed or worked around, and re-enable it again when its stable

jellewie, 2020-09-10:
https://github.com/espressif/arduino-esp32/issues/3740 'No CaptivePortal page comes up on ESP32 Dev. board'
https://github.com/espressif/arduino-esp32/pull/4080 'Update CaptivePortal.ino'
https://github.com/espressif/arduino-esp32/issues/4222 'The example of 'CaptivePortal' crashed my ESP on connect'

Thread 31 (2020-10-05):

Tasklist spacer and X marker not visible on black

jellewie, 2020-10-05:
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

jespertheend, 2020-12-13:
fixed with b6ed57c

Closed 2020-12-13.

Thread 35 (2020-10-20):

Update schematic

jellewie, 2020-10-20:
Updated schematic and PCB, and add these in the folder

jellewie, 2020-10-20:
Schematic on EASYEDA is the most updated one,
Round V1.2 has been tested, Round V1.3 but in old config mode also works (no noise suppression)

For the square wall models, non have been tested yet, but the schematic is the same and should work. I'm waiting on the delivery of these

Closed 2020-10-21.

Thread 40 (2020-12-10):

Analog hours wrong

jellewie, 2020-12-10:
@rudolfc noted that the analog clock uses MM/15 instead of MM/12

https://github.com/jellewie/Arduino-Smart-light/blob/master/Arduino/Clock.h#L91

`ClockHH += (TimeCurrent.MM / 15);`

rudolfc, 2020-12-18:
Jelle, kan dus dicht ;-)

Closed 2020-12-18.

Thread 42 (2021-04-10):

Daylight saving time not auto applied

jellewie, 2021-04-10:
Daylight saving time is not automatically applied and removed, although the offset time (3600) has been set.

The default ESP32 time library is used (if I'm not wrong) so who doesn't it do this? is there a config error (do we need to set dates, or enable it?) or is this really a bug?

https://github.com/jellewie/Arduino-Smart-light/blob/4e2bdca7e8c97ab514b5bf7a0a8bff4dde339aa7/Arduino/Clock.h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
https://www.cplusplus.com/reference/ctime/tm/ notes something about a 'tm_isdst' being set?
https://www.cplusplus.com/reference/ctime/localtime/

jellewie, 2021-04-10:
Should be fixed, but is untested, but ATM the time is right

Date 2021-04-10 (DST enabled)
daylightOffset_sec = 3600
Current time = 13:22 (Right)

when daylightOffset_sec changed to 0 (and synctime is called), the offset is removed (12:22) as should.

jellewie, 2023-03-13:
The date applied is the US date

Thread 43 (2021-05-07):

ClockAnalog flow around

jellewie, 2021-05-07:
So I removed some code I didn't know what it would do, but now I do and I see the issue.

ClockAnalog has an formula exp(-2,7 *x)*255 or something. But for when it's at the start/begin, the curve is wrong since it does not wrap around.
I fixed this my moving it +30 and then -30 so the curve would piek/curve would always be in vieuw.

Isue now: ClockAnalog does not wrap around nicely at LED[0] and LED[59]

Closed 2021-05-08.

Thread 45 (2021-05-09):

Animation blink clock

jellewie, 2021-05-09:
The animation for blink clock (120 clock leds 2 sections) does only do around 3/4 of the leds (270 degrees) and then the time is up

The formula should be adjusted

jellewie, 2021-05-10:
```
EVERY_N_MILLISECONDS((10000 / TotalLEDsClock) - 1) {
  LED_Blink(0, TotalLEDsClock, AnimationRGB, 1, &_Counter, _Direction);
  UpdateLEDs = true;
}
```

So each LED will take (10000/120)-1 = 83.333 = 83 ms
with 120 lEDs it would take 120*83= 9960ms or 9.996seconds to go around

The math seems fine, so not sure what the issue is yet...

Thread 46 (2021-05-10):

SECTIONS issues

jellewie, 2021-05-10:
Their still some issues with sections, for example no support have been implemented for

- ShowIp
- WiFi status feedback (startup, Apmode, connected)
- Synctime

These should should use the LEDs in the clock only, not use TotalLEDs

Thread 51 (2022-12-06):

PAO_LED used instead of LED_BUILTIN

jellewie, 2022-12-06:
https://github.com/jellewie/Arduino-Smart-light/blob/8ed5d5903221991f7bef18bf2fac54cb034e65dc/Arduino/Arduino.ino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

uses "PAO_LED", so when you us the button it will inter fear with the FastLED led commands. The LED_BUILTIN should have bene connacted to it

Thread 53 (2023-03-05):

Home Assistant integration

jellewie, 2023-03-05:
I want to integrate the lamp into Home Assistant, but don't know exactly how yet.

For now you can use this, where "192.168.1.255" is the IP of the lamp:
```
light:
  - platform: template
    lights: #https://www.home-assistant.io/integrations/light.template/
      smartclock:
        turn_on:
          service: rest_command.smartclock_on
        turn_off:
          service: rest_command.smartclock_off
        set_level:
          service: rest_command.smartclock_brightness
          data:
            brightness: "{{ brightness }}"
rest_command: #https://www.home-assistant.io/integrations/rest_command/
  smartclock_on:
    url: http://192.168.1.255/set?m=ON&r=255&g=200&b=100&s=2
    verify_ssl: false
  smartclock_off:
    url: http://192.168.1.255/set?m=clock&1=true
    verify_ssl: false
  smartclock_brightness:
    url: http://192.168.1.255/set?l={{brightness}} #https://community.home-assistant.io/t/switch-with-rest-command/154762/2
    verify_ssl: false
```
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

Currently, it's configured with "s=2" with means it only does the not-clock section. Remove the "&s=2" to make it change all LEDs. See
https://github.com/jellewie/Arduino-Smart-light/blob/ff45a61ef0f196b925e764d9e2b6ba6c03132d79/Arduino/handler.ino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

Currently, it's set up to change the RGB with "r=255&g=200&b=100", but your own settings can be put in. no RGB support yet (HA withs with Hue/saturation and I haven't been bordered to figure that out yet.

wjtje, 2023-03-06:
Maybe the best way to integrate your own code into Home Assistant is using MQTT.

Your code can send an MQTT Discovery to Home Assistant so it will be auto discovered and configured ([docs](https://www.home-assistant.io/integrations/mqtt/#mqtt-discovery)), and it can send state changes to Home Assistant.

jellewie, 2024-02-28:
Got a lot of it working in MQTT, but Still some things to fix/do

- [ ] can byte mac[] be not-static?
- [ ] fix setConfigurationUrl
- [ ] when onStateCommand1(OFF), let it change back the mode. and restore AutoBrightness?
- [ ] Update the (other) light to HA at the right moments
- [ ] How to send RGB data to HA? the color is sometimes a mismatch
- [ ] How to send Brightness data to HA? the Brightness is sometimes a mismatch

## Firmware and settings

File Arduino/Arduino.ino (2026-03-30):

/*Written by JelleWho https://github.com/jellewie
  TODO:  https://github.com/jellewie/Arduino-Smart-light/issues

  2023-07-24 PAO_MIC is on the SAME pin as PAI_B, so both can not be active at the same time. We need ADC1 if we also use WiFi

  These are  my verions, you can try your own/newer ones
  Arduino IDE 2.3.4     https://www.arduino.cc/en/software/
  DOIT ESP32 DEVKIT V1  https://dl.espressif.com/dl/package_esp32_index.json"
  FastLED 3.10.3        https://github.com/FastLED/FastLED
  ArduinoHA 2.10.0      https://github.com/dawidchyrzynski/arduino-home-assistant/tree/main
*/
#if !defined(ESP32)
#error "Please check if the 'DOIT ESP32 DEVKIT V1' board is selected, which can be downloaded at https://dl.espressif.com/dl/package_esp32_index.json"
#endif

//==============================================================//Note spacer

//#define SerialEnabled
#ifdef SerialEnabled
#define     WiFiManager_SerialEnabled                           //WM:
#define     Server_SerialEnabled                                //SV:
#define     Task_SerialEnabled                                  //TK:
#define     Time_SerialEnabled                                  //TM:
#define     SetupTime_SerialEnabled                             //ST:
#define     OTA_SerialEnabled                                   //OTA:
#define     RGBL_SerialEnabled                                  //RG:
#define     Animation_SerialEnabled                             //AN
#define     HomeAssistant_SerialEnabled                         //HA
//#define     Audio_SerialEnabled                               //AU:
//#define     LoopTime_SerialEnabled                            //LT:
//#define     TimeExtra_SerialEnabled                           //TME:
//#define     UpdateLEDs_SerialEnabled                          //UL:
//#define     Convert_SerialEnabled                             //CV:
//#define     LEDstatus_SerialEnabled                           //LS:
#endif //SerialEnabled

#define LED_TYPE WS2812B                                        //WS2812B for 5V LEDs, WS2813 for 12V LEDs
const char* ntpServer = "pool.ntp.org";                         //The server where to get the time from
const byte PAO_LED = 25;                                        //To which pin the <LED strip> is connected to
const byte PAO_MIC = 34;                                        //To which pin the <LED strip> is connected to
const byte PAI_R = 32;                                          //               ^ <Red potmeter> ^
const byte PAI_G = 33;                                          //
const byte PAI_B = 34;                                          //
const byte PAI_Brightness = 35;                                 //
const byte PDI_Button = 26;                                     //Pulled down with 10k to GND
const byte PAI_LIGHT = 39;                                      //Pulled down with a GL5528 to GND, and pulled up with 10k, This sensor is for AutoBrightness
const byte PAI_DisablePOTs = 4;                                 //Intern pulled up, when pulled down disableds reading of POTS
const byte PAI_OtherDefault  = 5;                               //Intern pulled up, when pulled down disableds reading of POTS

#include "Structs.h"
byte BootMode = CLOCK;                                          //SOFT_SETTING In which mode to start in
byte HourlyAnimationS = 10;                                     //SOFT_SETTING If we need to show an animation every hour if we are in CLOCK mode, defined in time in seconds where 0=off
byte DoublePressMode = RAINBOW;                                 //SOFT_SETTING What mode to change to if the button is double pressed
bool AutoBrightness = true;                                     //SOFT_SETTING If the auto brightness is enabled
bool AudioLink = false;                                         //SOFT_SETTING If the AudioLink is enabled
bool StandAlone = false;                                        //SOFT_SETTING If the StandAlone is enabled
float AutoBrightnessP = 1.04;                                   //SOFT_SETTING Brightness = y=255-(P*(x-N)-O) https://www.desmos.com/calculator/lmezlpkwsp
byte AutoBrightnessN = 10;                                      //SOFT_SETTING ^                        [Just the lowest raw sensor value you can find]
byte AutoBrightnessO = 5;                                       //SOFT_SETTING ^                        [Just an brigtness offset, so it can be set to be globaly more bright]
byte ClockHourLines = 0;                                        //SOFT_SETTING how bright each hour mark needs to be (0 for off)
bool ClockHourAnalog = false;                                   //SOFT_SETTING If the clock needs to display the hour with 60 steps instead of 12 full hour steps
byte LEDOffset = 0;                                             //SOFT_SETTING Number of LEDs to offset/rotate the clock, so 12 o'clock would be UP. Does NOT work in Animations
bool ClockAnalog = false;                                       //SOFT_SETTING Makes it so the LEDs dont step, but smootly transition
String timeZone = "CET-1CEST,M3.5.0,M10.5.0/3";                 //SOFT_SETTING Set to you Timezone, see https://github.com/nayarsystems/posix_tz_db/blob/master/zones.csv
byte PotMinChange = 2;                                          //SOFT_SETTING How much the pot_value needs to change before we process it
byte PotStick = PotMinChange + 1;                               //SOFT_SETTING If this close to HIGH or LOW stick to it
byte PotMin = PotMinChange + 2;                                 //SOFT_SETTING On how much pot_value_change need to change, to set mode to manual
char Name[16] = "smart-clock";                                  //SOFT_SETTING The mDNS, WIFI APmode SSID name. This requires a restart to apply, can only be 16 characters long, and special characters are not recommended.
float AudioMultiplier = 2;                                      //SOFT_SETTING Howmuch to amplify the input signal (Idealy when loud the ouput should be 255)
int AudioAddition = 0;                                          //SOFT_SETTING Howmuch to add to the input signal
byte MinAudioBrightness = 1;                                    //SOFT_SETTING Minimum amount of brighness that will be applied with Audiolink
byte MaxAudioBrightness = 255;                                  //SOFT_SETTING Maximum amount of brighness that can be applied with Audiolink
byte AmountAudioAverageEnd = 6;                                 //SOFT_SETTING howmuch to smooth the LEDs responoce (Its after the math)(Max 64! recomended to keep low like 3-5)
byte AudioRawLog[255];                                          //Used to log raw audio sensory data in
const byte AudioLog_Amount = sizeof(AudioRawLog) / sizeof(AudioRawLog[0]);//Why filling this in if we can automate that? :)
byte AudioLog[AudioLog_Amount];                                 //Used to log audio sensory data in
int EveryXmsMic = 10;                                           //SOFT_SETTING Pulling rate of MIC, Delay the amount where the average is based on, this results in 16*10ms = the last 0.16 seconds
bool UpdateLEDs;                                                //If we need to physically update the LEDs
bool TimeSet = false;                                           //If the time has been set or synced, is used to tasked based on time
byte Mode;                                                      //Holds in which mode the light is currently in
byte LastMode = -1;                                             //Just to keep track if we are stepping into a new mode, and need to init that mode. -1 to force init
const int TotalLEDs = 60;                                       //The total amounts of LEDs in the strip
#define LEDSections TotalLEDs / 60                              //Amount of sections of LEDs for the Clock (2=each step is 2 LEDs so 12h=120+121 LED, 1=Default 12h=60th LED)
//const int16_t TotalLEDs = 300;                                  //The total amounts of LEDs in the strip
//#define LEDSections 2                                           //Amount of sections of LEDs for the Clock (2=each step is 2 LEDs so 12h=120+121 LED, 1=Default 12h=60th LED)
const int TotalLEDsClock = LEDSections * 60;                    //The amount of LEDs in the clock
int AnimationCounter;                                           //Time in seconds that a AnimationCounter Animation needs to be played
TimeS TimeCurrent;                                              //Where we save the time to
byte ModeBeforeOff = ON;
extern byte TotalAnimations;                                    //^ Required for Clock.h
extern void StartAnimation(byte ID, int Time);                  //^ Required for Clock.h
struct tm timeinfo;                                             //https://www.cplusplus.com/reference/ctime/tm/ (Blobal here to make accesable for debug '/info' page)

#include <WiFi.h>
#include "WiFiManagerBefore.h"                                  //Define what options to use/include or to hook into WiFiManager
#include "WiFiManager/WiFiManager.h"                            //Includes <WiFi> and <WebServer.h> and setups up 'WebServer server(80)' if needed      https://github.com/jellewie/Arduino-WiFiManager

#include <FastLED.h>                                            //Include the libary FastLED (If you get a error here, make sure it's installed!)
CRGB LEDs[TotalLEDs];
CRGB RGBColor;

#include "Button/Button.h"
Button ButtonsA = {PDI_Button, INPUT, LED_BUILTIN};

#define StableAnalog_AnalogResolution 10                        //ESP32 does not support 8bit (byte) analog readings, to set to 10 and scale down to 8
#include "StableAnalog/StableAnalog.h"
StableAnalog RED   = StableAnalog(PAI_R);
StableAnalog GREEN = StableAnalog(PAI_G);
StableAnalog BLUE  = StableAnalog(PAI_B);
StableAnalog BRIGH = StableAnalog(PAI_Brightness);
StableAnalog LIGHT = StableAnalog(PAI_LIGHT);
StableAnalog AUDIO = StableAnalog(PAO_MIC);

extern void HAUpdateLED(bool Force = false);                    //We declair this funcion in "MQTT_HA.h"
#include "functions.h"
#include "MQTT_HA.h"
#include "time.h"                                               //We need this for the clock function to get the time (Time library)
#include "Task.h"
#include "WiFiManagerLater.h"                                   //Define options of WiFiManager (can also be done before), but WiFiManager can also be called here (example for DoRequest)
#include "Clock.h"
#include "Animation.h"

void setup() {
#ifdef SerialEnabled
  Serial.begin(115200);
  Serial.setTimeout(1);
#endif //SerialEnabled
  //===========================================================================
  //Init LED and let them shortly blink
  //===========================================================================
  FastLED.addLeds<LED_TYPE, PAO_LED, GRB>(LEDs, TotalLEDs);
  FastLED.setBrightness(1);                                     //Set start brightness to be amost off
  for (int i = 255; i >= 0; i = i - 255) {                      //Blink on boot
    fill_solid(&(LEDs[0]), TotalLEDs, CRGB(i, i, i));
    FastLED.show();                                             //Update
    FastLED.delay(1);
  }
  //===========================================================================
  //Set and attach pins
  //===========================================================================
  attachInterrupt(ButtonsA.PIN_Button, ISR_ButtonsA, CHANGE);
  pinMode(PAI_DisablePOTs, INPUT_PULLUP);                       //Pull the pin up, so the pin is by default HIGH if not attached
  if (digitalRead(PAI_DisablePOTs) == HIGH)                     //If the POTs are enabled with hardware
    AudioLink = false;                                          //Do not allow AudioLink if Pots are enabled
  //===========================================================================
  //Set default settings
  //===========================================================================
  pinMode(PAI_OtherDefault, INPUT_PULLUP);                      //Pull the pin up, so the pin is by default HIGH if not attached
  if (digitalRead(PAI_OtherDefault) == LOW) {                   //If the pin is pulled low by hardware, Change the default of some SOFT_SETTINGs
    BootMode = CLOCK;
    DoublePressMode = CLOCK;
  }
  //===========================================================================
  //Set up all server UrlRequest stuff
  //===========================================================================
  server.on("/",            handle_OnConnect);                  //Call the 'handleRoot' function when a client requests URL "/"
  server.on("/main",        handle_Main);
  server.on("/get",         handle_Getcolors);
  server.on("/set",         handle_Set);
  server.on("/gettasks",    Tasks_handle_GetTasks);
  server.on("/settask",     Tasks_handle_Settings);
  server.on("/time",        handle_UpdateTime);
  server.on("/info",        handle_Info);
  server.on("/reset",       handle_Reset);
  server.onNotFound(        handle_NotFound);                   //When a client requests an unknown URI
  //===========================================================================
  //Init the potmeters (This trashed their first values)
  //===========================================================================
  //analogReadResolution(StableAnalog_AnalogResolution);
  for (int i = 0; i < StableAnalog_AverageAmount + 2; i++) {
    UpdateColor(false);                                         //Trash some measurements, so we get a good average on start
    UpdateBrightness(false);
    AUDIO.ReadStable();
  }
  FastLED.setBrightness(8);                                     //Set boot Brightness
  //===========================================================================
  //Add a SYNCTIME Task, this is just to initialise (will be overwritten with user data)
  //===========================================================================
  TASK TempTask;                                                //Create a space to put a new Task in
  TempTask.Type       = SYNCTIME;                               //Set the ID of the task to SYNCTIME
  TempTask.ExectuteAt = TimeS{4, 0, 0, 0};                      //Set the init value to auto sync time at 04:00:00
  AddTask(TempTask);                                            //Add the Task command to the task list
  //===========================================================================
  //Load data from EEPROM, so we can apply the set bootmode
  //===========================================================================
  WiFiManager.LoadData();
  Mode = BootMode;                                              //Set the startup mode
#ifdef SerialEnabled
  Serial.println("SE: Booting up in mode " + String(Mode) + "=" + ConvertModeToString(Mode));
#endif //SerialEnabled
  loopLEDS();
  UpdateBrightness(true);                                       //Force Update the brightness
  if (HA_MQTT_Enabled_On_Boot)
    HA_MQTT_Enabled = true;
#ifdef SetupTime_SerialEnabled                                  //Just a way to measure setup speed, so the performance can be checked
  Serial.println("ST: Setup took ms:\t" + String(millis()));
#endif //SetupTime_SerialEnabled
}
void loop() {
#ifdef LoopTime_SerialEnabled                                   //Just a way to measure loop speed, so the performance can be checked
  static unsigned long LoopLast = 0;
  unsigned long LoopNow = micros();
  float LoopMs = (LoopNow - LoopLast) / 1000.0;
  LoopLast = LoopNow;
  Serial.println("LT: Loop took ms:\t" + String(LoopMs));
#endif //LoopTime_SerialEnabled
  WiFiManager.RunServer();                                      //Do WIFI server stuff if needed
  if (StandAlone) StandAloneAPMode();
  if (TimeSet and Mode != CLOCK) UpdateAndShowClock(false);     //If we are not in clock mode but the time has been set, update the internal time before ExecuteTask
  ExecuteTask();
  if (AnimationCounter != 0)                                    //Animation needs to be shown
    ShowAnimation(false);
  if (HA_MQTT_Enabled) {                                        //If we need to talk to MQTT
    if (HA_MQTT_Enabled_old != HA_MQTT_Enabled)                 //If this is the first time
      HaSetup();
    HaLoop();
  }
  HA_MQTT_Enabled_old = HA_MQTT_Enabled;
  EVERY_N_MILLISECONDS(1000 / 60) {                             //Limit to 60FPS
    Button_Time Value = ButtonsA.CheckButton();                 //Read buttonstate
#ifdef SerialEnabled                                            //DEBUG, print button state to serial
    if (Value.StartPress)       Serial.println("StartPress");
    if (Value.StartLongPress)   Serial.println("StartLongPress");
    if (Value.StartDoublePress) Serial.println("StartDoublePress");
    if (Value.StartRelease)     Serial.println("StartRelease");
#endif //SerialEnabled
    if (Value.StartPress) {
      if (Mode == OFF) {
        if (ModeBeforeOff == OFF)                               //If (ModeBeforeOff is OFF) then {set mode to be ON} else {set to ModeBeforeOff}
          Mode = ON;
        else
          Mode = ModeBeforeOff;
      } else {
        ModeBeforeOff = Mode;
        Mode = OFF;
      }
    }
    if (Value.StartDoublePress)
      Mode = DoublePressMode;                                   //Cool RGB color palet mode
    if (Value.StartLongPress) {
      Mode = WIFI;
      if (WiFi.status() == WL_CONNECTED) {                      //If WIFI was already started
        ShowIP();
        LastMode = Mode;
      }
    };
    if (Value.PressedLong) {                                    //If it is/was a long press
      if (Value.PressedTime > Time_ESPrestartMS - 1000)         //If we are almost resetting
        Mode = RESET;
    }
    UpdateBrightness(false);                                    //Check if manual input potmeters has changed, if so flag the update
    UpdateAudio(false);                                         //Check if the AudioLink is needed
    UpdateColor(false);                                         //Check if manual input potmeters has changed, if so flag the update
    loopLEDS();
  }
}
void loopLEDS() {
  switch (Mode) {
    case OFF: {
        if (LastMode != Mode) {
          AnimationCounter = 0;
          FastLED.clear();
          UpdateLEDs = true;
        }
      } break;
    case ON: {
        if (LastMode != Mode) {                                 //If mode changed
          AnimationCounter = 0;
          UpdateColor(true);
        }
      } break;
    case WIFI: {
        if (LastMode != Mode) {                                 //If mode changed
          AnimationCounter = 0;
          WiFiManager.Start();                                  //Start WIFI if we haven't
        }
      } break;
    case RESET: {
        if (LastMode != Mode) {                                 //If mode changed
          AnimationCounter = 0;
        }
        EVERY_N_MILLISECONDS(50) {
          LED_Flash(0, TotalLEDs, CRGB(255, 0, 0));             //Toggle the leds RED/OFF to show we are restarting soon
          UpdateLEDs = true;
        }
      } break;
    case CLOCK: {
        if (LastMode != Mode) {                                 //If mode changed
          AnimationCounter = 0;
          if (WiFi.status() != WL_CONNECTED) {                  //If no WiFi has been set-up
            if (!TimeSet)                                       //If the time has not been set before
              WiFiManager.Start();                              //Start WIFI if we haven't
            else
              WiFiManager.CheckAndReconnectIfNeeded(false);     //Try to connect to WiFi, but dont start ApMode
          }
        }
        if (AnimationCounter == 0)                              //If no (hourly) animation is playing
          UpdateAndShowClock(true);
      } break;
    case STANDALONE:
      if (LastMode != Mode)
        StandAlone = true;
      WiFiManager.EnableSetup(true);                            //Enable setup page
      Mode = RAINBOW;
      StartAnimation(7,  -2);
      break;
    default:
      uint8_t AnimationID = Mode - 5;
      if (AnimationID < TotalAnimations){
        if (LastMode != Mode) StartAnimation(AnimationID, -2); break;
      } else {
#ifdef SerialEnabled
        Serial.println("mode with ID " + String(Mode) + " not found");
#endif //SerialEnabled
        Mode = ON;
        AnimationCounter = 0;                                   //Stop animation
        break;
      }
  }
  LastMode = Mode;
  UpdateLED();
}
//ISR must return nothing and take no arguments, so we need this sh*t
void ISR_ButtonsA() {
  ButtonsA.Pinchange();
}

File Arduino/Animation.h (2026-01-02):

/* Written by JelleWho https://github.com/jellewie

  =====How to add an animation=====
  Animation.h:  Add the funtion to 'ShowAnimation::switch (CurrentAnimation)' as a new case 'case x+1: {the code}  break;'.
                'AnimationRGB' can be used for the user set RGB color
                'Start' Can be used to detect the start of the animation
                Note that 'UpdateLEDs = true;' must be set to update the leds
  Animation.h:  Update 'TotalAnimations' to be x+1 (Note the SwitchCase counts from 0, not 1)
  Structs.h:    Add to 'String ModesString[] = {', it needs a uniquee name! and needs to be in CAPS!
                Also add to 'enum Modes {'
  handler.ino:  Add to webinterface by 'let Dm=.....possibleValues:['   (This is a to long string to automate it, sorry)
*/
byte CurrentAnimation;                                          //Which AnimationCounter Animation is selected
byte TotalAnimations = 17;
CRGB AnimationRGB = {0, 0, 0};

//==================================================
//Basic universal LED functions can be found in Functions.h
//
//And some not universal LED functions:
//==================================================
bool AnimationSinelon(CRGB rgb, byte DimBy, byte BPM) {         // a colored dot sweeping back and forth, with fading trails
  //byte rgb[3] = {255, 0, 0};                                  //The color value
  //byte DimBy = 2;                                             //Delay in ms to fade to black
  //Returns true if this is the start
  fadeToBlackBy(LEDs, TotalLEDsClock, DimBy);
  byte pos = beatsin8(BPM, 0, TotalLEDsClock - 1);
  LEDs[LEDtoPosition(pos)] += rgb;
  static byte Lastpos;
  if ((pos == 0 or pos == TotalLEDsClock - 1) and Lastpos != pos) { //If we just ended
    Lastpos = pos;
    return true;
  }
  Lastpos = pos;
  return false;
}
//==================================================
//End of LED functions
//==================================================
void SetNewColor() {                                            //Sets 'AnimationRGB[]' to a new color, so the Animation would change color
  AnimationRGB.r = 0; AnimationRGB.g = 0; AnimationRGB.b = 0;   //Clear animation color, so we can set a new one
  switch (random8(0, 6)) {
    case 0: AnimationRGB.r = 255;                                               break;
    case 1:                       AnimationRGB.g = 255;                         break;
    case 2: AnimationRGB.r = 255; AnimationRGB.g = 255;                         break;
    case 3:                                               AnimationRGB.b = 255; break;
    case 4: AnimationRGB.r = 255;                         AnimationRGB.b = 255; break;
    case 5:                       AnimationRGB.g = 255;   AnimationRGB.b = 255; break;
  }
}
//==================================================
void ShowAnimation(bool Start) {                                //This would be called to show an Animation every hour
  EVERY_N_SECONDS(1) {
    if (AnimationCounter != -1)
      AnimationCounter = AnimationCounter - 1;
#ifdef Animation_SerialEnabled
    Serial.println("AN: AnimationCounter=" + String(AnimationCounter));
#endif //Animation_SerialEnabled
  }
  switch (CurrentAnimation) {
    case 0: {                                                   //BLINK
        static byte _Counter;
        static bool _Direction;
        static bool _GoingOn;
        if (Start) {
          _Counter = 0;
          _GoingOn = true;
          _Direction = random8(0, 2);
        }
#define ANIMATION_TIME_BLINK (10000 / TotalLEDsClock) - 1
        EVERY_N_MILLISECONDS(ANIMATION_TIME_BLINK) {            //Make it so it does a full round every 10s
          if (_GoingOn)
            LED_Blink(LEDtoPosition(0), TotalLEDsClock, AnimationRGB, 1, &_Counter, _Direction, true, TotalLEDsClock);
          else
            LED_Blink(LEDtoPosition(0), TotalLEDsClock, CRGB(0, 0, 0), 1, &_Counter, _Direction, false, TotalLEDsClock);
          if (_Counter == 0)
            _GoingOn = !_GoingOn;
          UpdateLEDs = true;
        }
      } break;
    case 1: {                                                   //BPM
        CRGBPalette16 palette = PartyColors_p;                  //(const CRGBPalette16 &pal, uint8_t index, uint8_t brightness=255, TBlendType blendType=LINEARBLEND)
        byte beat = beatsin8(20, 64, 255);
        const byte gHue = 9;
        for (int i = 0; i < TotalLEDsClock; i++)
          LEDs[i] = ColorFromPalette(palette, gHue + (i * 2), beat - gHue + (i * 10));
        UpdateLEDs = true;
      } break;
    case 2: {                                                   //CONFETTI
        if (Start) ClockClear();
#define ANIMATION_TIME_CONFETTI 1000 / 60
        EVERY_N_MILLISECONDS(ANIMATION_TIME_CONFETTI) {         //Limit to x FPS
          fadeToBlackBy(LEDs, TotalLEDsClock, 1);               //Dim a color by (X/256ths)
          EVERY_N_MILLISECONDS(50) {
            LEDs[random(TotalLEDsClock)] += AnimationRGB;
          }
          SetNewColor();
          UpdateLEDs = true;
        }
      } break;
    case 3: {                                                   //FLASH
        if (Start) ClockClear();
        EVERY_N_MILLISECONDS(500) {
          LED_Flash(0, TotalLEDsClock, AnimationRGB);
          UpdateLEDs = true;
        }
      } break;
    case 4: {                                                   //GLITTER
        if (Start) ClockClear();
#define ANIMATION_TIME_GLITTER 1000 / 60
        EVERY_N_MILLISECONDS(ANIMATION_TIME_GLITTER) {          //Limit to x FPS
          fadeToBlackBy(LEDs, TotalLEDsClock, 1);               //Dim a color by (X/256ths)
          if (random8() < 40)                                   //x/255 change to exectue:
            LEDs[random(TotalLEDsClock)] += AnimationRGB;
          UpdateLEDs = true;
        }
      } break;
    case 5: {                                                   //JUGGLE
        if (Start) ClockClear();
#define ANIMATION_TIME_JUGGLE 1000 / 120
        EVERY_N_MILLISECONDS(ANIMATION_TIME_JUGGLE) {           //Limit to x FPS
          fadeToBlackBy(LEDs, TotalLEDsClock, 10);
          byte dothue = 0;
          for (byte i = 0; i < 8; i++) {
            LEDs[LEDtoPosition(beatsin8(i + 7, 0, TotalLEDsClock))] |= CHSV(dothue, 200, 255); //CHSV = 'angle' (of color wheel), Saturation(rich/pale), 'bright'
            dothue += 32;
          }
          UpdateLEDs = true;
        }
      } break;
    case 6: {                                                   //MOVE
        static byte _Sets, _Length, _Counter;
        static bool _Direction;
        if (Start) {
          _Sets = random8(2, 9);
          _Length = random(2, TotalLEDsClock / (_Sets + 1));
          _Direction = random8(0, 2);
        }
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

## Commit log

2020-06-13 WIP! init
    [Assembly.iam, Lamp body.ipt, Lamp body.stl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]
2020-06-13 Added a bit more room for the LED strip
    And added a room to hide the wires in
    [Assembly.0029.iam, Assembly.iam, Lamp body.0032.ipt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]
2020-06-13 Some left behind 3D file updates
    [Assembly.0029.iam, Assembly.iam, Lamp body.0032.ipt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]
2020-06-22 More bug fixes + grammer and layout fixes
    [Arduino.ino, Time.ino, handler.ino]
2020-06-22 Fix some grammer, lowered long press time
    [Arduino.ino]
2020-07-02 small grammer fixes and improvements
    [Arduino.ino, Time.ino]
2020-07-02 Now allows to exit APMode (long press button)
2020-07-02 Now allows to exit APMode
    Long press the button to exit
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2020-07-08 Added sync option in rare cases to the button
    It will only sync time when in ClockMode and the double press is also set to ClockMode (And WIFI is on)
2020-07-08 some tiny erros solved
    [Arduino.ino]
2020-07-26 Thnx to @JesperTheEnd fixed colors shown on server
    [handler.ino]
2020-07-26 Fixed some line enters, updated manual, and added /version
    */version will show the date and time the code has been compiled
    [Arduino.ino, Task.h]
2020-07-26 New updated model of PCB version
    Printing a complete on right now, but the prototypes seem to indidate its all good
    [Assembly.iam, Body.stl, Clock Top.stl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]
2020-07-27 LED_TYPE is now an option
2020-07-27 Added mDNS (still needs to be checked)
    The ESP now should be accesable on 'esp32.local'
2020-07-27 MDNS and MAc/IP info works
    please see 'esp32.local/info'
2020-07-27 Fixed the display of the IP in /info
    [handler.ino]
2020-07-29 Now the ShowIP is 30s and can be skipped with a button
    The next IP number will be shown after 30 seconds, and can be skipped with a button press
2020-07-29 Updated the Schematic, I suggest going to EASYEDA for the newest everytime
2020-07-29 Consept of printing a diffuser
    [Difuser.stl, Lamp.ipt]
2020-07-29 Fixed RGB order again
    [Arduino.ino]
2020-07-31 fixed desktop shown RGB color
    Also shorten name to reduce bytes
    [handler.ino]
2020-08-03 Bugfixes + more web-options + Captive portal
    So much things, just start with the captive portal, but after 4 hours solved so many tiny bugs everywhere, that I cant be borthered to not make more than 1 commit for it.
    [Arduino.ino, handler.ino]
2020-08-04 add info button to client settings screen
2020-08-10 Disabled DNSServer, seems to be to unstable for now
    [Arduino.ino, handler.ino]
2020-08-11 Thicker shield (now 3mm)
    [Lamp.ipt, shield.stl]
2020-08-11 Added smart clock PCB link #13
2020-08-12 Possible fix for #3 and improved time engine
    [Clock.ino, handler.ino]
2020-08-12 Added cable gap back in Shield
    [Lamp.ipt, shield.stl]
2020-08-12 Readme is now the manual + restructure
    [Assembly.iam, Body.stl, Clock Top.stl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]
2020-08-12 Some small fixes for readme
    [handler.ino]
2020-08-13 Added LED status to readme
2020-08-13 Added ClockCantSync to LED blink
2020-08-13 Fixed; blink if NOT connected
    [Clock.ino]
2020-08-13 Updated to the same version that is used in Arduino
2020-08-13 Fixed for the forced clock mode, now you can exit it again
    [Clock.ino]
2020-08-17 Added 'WIFI Apmode' LED
2020-08-19 Added timeout (10 seconds) to UpdateTime
    https://github.com/espressif/arduino-esp32/blob/master/cores/esp32/esp32-hal-time.c#L80
    'bool getLocalTime(struct tm * info, uint32_t ms)'
2020-08-20 Made boot led color consistance, and reduced boot time to below 1 second (641ms inc wifi+clock)
2020-08-24 Updated website on th Arduino side
2020-08-28 Fixed 'remove task' is missing 'TaskID'
    [Task.h]
2020-09-04 #e4fdc7c is now included in Arduino code #21
2020-09-07 Fixed to include end of list, returns -1 as failed
    [Task.h]
2020-09-07 Draft of TASK save to EEPROM
    Seems to work now, but there where some weird errors...
    [Task.h, handler.ino]
2020-09-07 Task fixes, and added SYNCTIME as a Task
    now SYNCTIME is saved at slot 0 in the tasklist, this is just a init value and can be overwritten by the user (thus also changed)
    [Arduino.ino, Clock.ino, Task.h]
2020-09-07 Fixed bug, need to convert to int first
    [Task.h]
2020-09-17 Just last comment in preperation of @jespertheend
    nothing fancy, just changed some naming,
    and added a replace backspace in strings
    [Task.h, handler.ino]
2020-10-02 STL shield was out of sync
    [Shield.stl]
2020-10-02 Revert "STL shield was out of sync"
    This reverts commit 5450356613cae662c7cf80a485ca00b62df6aadf.
    [Shield.stl]
2020-10-09 Added /reset option
    This will FULLY clear EEPROM and all user settings
    [Arduino.ino, handler.ino]
2020-10-09 Updated Clock to more lib version
    also fixed #29
    [Clock.h, functions.h, handler.ino]
2020-10-09 Added 2 more animations
    note that smiley isn't moving yet, there where out of array bound erros I was unable to fix.
    [Animation.h, Arduino.ino, functions.h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]
2020-10-11 More animation fixes
    Fixes all known overflow issues.
    Added animation to SMILEY
    [Animation.h]
2020-10-14 Some small tweaks + SMILEY eye fix
    improves speed in animations loop, 'UpdateLEDs = true' MUST now be used to update the leds. else the update will be skipped
    [Animation.h]
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2020-10-19 Better wall model
    #33 The CNC version has no LED spacers, Im thinking about adding 3D printed ones, but this design is NOT yet finisched. altough it does seem to work (and is better than what is published now)
    [Assembly 3D printed only.iam, Assembly CNC.iam, Clock Top.stl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]
2020-10-21 Updated schematic and such #35
    now #35 can be closed
2020-10-22 Updated 3D models and Readme
    [Assembly 3D printed only.iam, Assembly.iam, Body.stl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]
2020-10-24 Made DC jack hole a tiny bit bigger (+0.2mm)
    [Body.stl, Desk.ipt]
2020-10-24 Updated WiFiManager and such
    Now also switches to BootMode after the APmode has set the WiFi stuff.
    Also the max upper bounds of some SOFTSETTINGS have been set (these are real bounds, not fake bounds I think are logic)
    Also WiFiManager_DNS has been enabled for the fist time, this feature might be unstable. But I have more hope this time
    OTA, DNS, mDNS have been intregraded into WiFiManager.
    ClockOffset is now by default 0, since this makes more sence (and all models are this way now)
    StartWIFIstuff() function has been made redundant and is now inside the WiFiManager
    [Arduino.ino, WiFiManager.cpp, handler.ino]
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2020-10-26 Small update
    WiFiManager_DNS was giving an unused variable warning, thats now fixed
    [Animation.h, Arduino.ino, WiFiManager.cpp]
2020-10-27 #36 fixed, relative tasks now work again
    TASK TempTask = TaskList[i]; //Create a space to put a new Task in
    [Arduino.ino, Task.h]
2020-10-27 #34 fixed OTA zoom on phones
    [WiFiManager.cpp]
2020-10-27 (Restore mode/off) on button press
2020-10-27 Fixes packman
    This also patches negative overflow
    [Animation.h, Clock.h]
2020-10-27 WiFiManager_DNS still crashes (now disabled again)
    I had another ESP32 which crased, I blame DNS for it
    [Arduino.ino]
2020-10-28 Added an Index and BOM
2020-10-28 Better overflow protection in LEDtoPosition
2020-10-29 Added hardware 'DisablePOTs' option
    pull pin 35 low (As schematic V1.5+) to disable the pot meters
2020-10-29 Added PAI_OtherDefault,
    This makes it so the default bootmode is CLOCK when the pin is pulled low (just the init default setting, now what the user overwrites it to)
2020-12-03 Added a IgnoreButtonPressTimeMs to MyDelay
    this trashes all button presses made in a certain period
2020-12-03 Renamed ClockOffset to LEDOffset
2020-12-03 Fixes a compiler warning
    [Arduino.ino]
2020-12-03 #39 adds support for more LEDsections in CLOCK mode
    This basicly multiplies the LEDs,
    For example when you have a section of 3 it means that LED 1+2+3 now behave as one section, and that the clock will treat them as such. Resulting in a clock with tripple the amount of LEDs in this ca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
    Default is stil 1 section, so 60 LEDs in total, this is just support for if you want to make a hardcoded bigger clock
2020-12-09 Updated WifiManager ~(formatting + small compiler things)
    Also fixes defaul scale of OTA page on phones
    [WiFiManager.cpp]
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2020-12-13 fix remove task button color not changing with the rest of the ui (#31)
2020-12-14 #b6ed57c #4df3a65 #02a0267 imported in Arduino sketch code
    has nog been compiled or tried yet, but has been checked and I think it was succesfull.
    Thnx @jespertheend
2020-12-14 Test
    Test to ignore STL files in language stats
2020-12-15 Updated to Chrome start layout
    This is now in Sync with arduino version again
2020-12-18 Fixed analog hour pointer to use all leds and not skip every last led before the 'whole hour' indication.
    [Clock.h]
2021-04-10 Possible DST fix #42
    [Clock.h]
2021-04-10 AutoBrightness round to nearest
    Round AutoBrightness to nearest instead of down
    Also fixed notes on formulas
    [Arduino.ino, StableAnalog.cpp, functions.h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]
2021-04-20 Updates and fixes
    Includes a huge setup fix.
    but also auto brightness scale is fixed (resolution was wrong, so it was 0=0% 1=50% 2=100% 3=0% 4=50% 5=100% (basically two times the scale)
    Updated libaries: Button, WiFiManager
    Fixed compilation error (wrong variable name used)
    Fixed debug serial format, so it compiles again with debug on
    [Arduino.ino, Button.cpp, Clock.h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]
2021-04-23 Fixed spacing code notations
    [Animation.h, Arduino.ino, Button.cpp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]
2021-05-04 Added better hybrid (Clock+Lamp) support
    Now I finally have such a unit (TotalLEDs=300, LEDSections = 2) I can tesst such things.
    My setup is 120 clock leds in the midle, and 180 more on a outer ring just for lamp duty
    also added section support for smiley face, only PACMAN is still left behind
2021-05-07 PACMAN fixed, patched Hybrid clock/lamp
    Better support for Hybrid LED strips,
    Fixed PACMAN mode for Sections + Offset
    [Animation.h, Clock.h, functions.h]
2021-05-07 Removed stuff I didn't understand
    [Clock.h]
2021-05-08 Added stuff back I didn't understand #43
    Now I know what it does, and we need it
    [Clock.h]
2021-05-10 fixes all issues of #46
    [Clock.h, functions.h]
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2021-05-18 Fixed hour location of ClopckAnalog
    [Clock.h]
2021-05-18 Better section suport
    Mostly for animations,
    But also added the "S" value to set only the colour of a section of the LEDs
2021-05-20 Fixed some timings, and made BLINK nicer
    [Animation.h, functions.h]
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2021-05-28 Do not ping WiFi each time the mode changes to clock
    This also solves the issue that APmode is started when the WiFi is not conneted but switching to the clock (and time has been set before)
    [Arduino.ino]
2021-06-07 Updated model refferences
    [Assembly.iam, Wall Clock CNC.stl, Wall Clock CNC.stp]
2021-06-07 RANDOMANIMATION + More tasks + Last task error
    Added task RANDOMANIMATION
    Save more Taks to eeprom (all 16 now)
    If the last task can not be scheduled, (list is full) run it now
    [Animation.h, Clock.h, Task.h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]
2021-06-28 multiple section: fixed blink over'flow'
    fixed an overflow into lamp LEDs in blink mode if multiple sections and an offset is used at the same time.
    This fix bounds the blink animation to be within the clock LEDs
    [Animation.h]
2021-07-02 Better section support, clear whole LED with whole LED command
2021-12-27 Support for bigger clocks
    now clocks with above 240 LEDs (4 sections) are (better) supported
    [Desk.ipt]
2023-03-13 Patch for #42
    Seems to work right now
    (currently US has DST, we don't yet)
2024-02-28 Fixed AudioRawLog out of bounds
    [Arduino.ino]
2025-10-13 Fix Linux compilation errors
    [Arduino.ino]
2025-12-29 Fix small AutoBrightness typos
    [MQTT_HA.h]
2025-12-30 Compile the HA mode options
    Less humon mistakes
    [MQTT_HA.h]
2025-12-30 Ignore elf and map files
    These are new output files of the Arduino IDE
